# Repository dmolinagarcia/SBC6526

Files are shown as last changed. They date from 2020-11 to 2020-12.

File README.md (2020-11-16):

## SBCv1.sch and SBCv1.brd

These files are the first "production " run of my SBC. It has some issues though:

1. Missing a 3K3 Pull-Up Resistor on the /IRQ line
2. Missing 4 3K3 Pull-Up Resistors on the 4 input buttons
3. LCD connector has to be soldered on the bottom of the PCB, as there's no space on top of it for the connector. Because of this, the cable connected to the LCD has all the even/odd wires interchanged. A quick hack, but works. v2 Will solve this
4. The two left stands for the LCD don't have space either on the PCB, so the build is a bit.. unstable.
5. The power jack is completely disposable. A arduino nano gives enough current for the SBC to work up to 15 Mhz

The adjustable clock works, but it tops at around 17 MHz, beyond that, it won't work at all.

LED2 and LED3 common cathod signals are reversed, solved on this version by cutting the traces and adding some bodge wires.

## TEST5.ino (and RAm595 library)
Arduino code to upload an image to ram. Arduino listens on the serial port for the following commands

- S         : Pulls BE low, disconnecting the 6502 from the bus and enabling the shift registers
- A 0000    : Sets the address bus to 0000
- R 0000    : Reads and returns over serial value at memory location 0000
- W 0000 00 : Writes 00 in memory location 0000
- X         : Pulls BE high, disabling the shift registers and reenabling the 6502. The CPU is then reset and code execution begins
- B 0000 00 000F : Bulk program, staring at 0000 for 000F bytes. Maximum is 1K (0400). Bytes sent to the arduino after this are written sequentially on memory

## RAMFLASHER.java
Java code to program a .bin file to the SBC. Right now, the address and source file are hardcoded.  Requires jSerialComm-2.6.1.jar

## SBC_TEST1.asm
- Current firmware. It implements basic IO functions. Handles the LCD screen with a movable window in memory (0x7000 - 0x7fff). Up and Down buttons move the window. All string funcitions move a virtual cursor through the memory map.
- LCD refresh is implemented via interrupts with VIA Timer. The whole screen is redraw 5 time per sec and the keyboard scanned.
- customizable calls are executed whenever any button is pressed. Memory Location 0x30 contains the pressed key to be read by software.

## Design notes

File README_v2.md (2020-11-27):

# SBC6526
A 6502 based SBC, capable of using a MOS6526, or the new replacement 74HCT6526

Being my first attempt at creating a SBC, v1 had many flaws. There were some pull-up resistors missing, the PCB layout was a mess, the bootstrap code was... well... unreadable to be honest. Moreover, the CAD tool I choose for v1, Eagle Cad, has a nasty licensing which is pulling away many users. I decided to make the transition to KiCAD for the v2. It's still a work in progress, and completely untested, but feel free to take a look if you like.

This readme will be updated as soon as new content is commited to the repository.

## BootStrap

The SBC6526 has no ROM. RAM exists between 0000-7FFF and C000-FFFF. As you know, the 6502 CPU needs the startup vectors to be present in the last segment of memory so, how does the SBC6526 boot?

An Arduino NANO handles the startup sequence. On startup, it brings BE low, disconnecting the 6502 from the address and data busses, and the R/W line. This also enables a pair of 8bit shift registers that handle from now on the address bus.

The RAM IC has 2 enable inputs. One is controled via the SBC Address Decoding logic, the other, directly by the ARDUINO. During BootStraping, RAMCE pulses with PHI2 (independent from the arduino) and the Arduino pulses CE line. This is a bit unorthodox and may cause some failures to write, if the arduino pulse happens when PHI2 is  high. This is handled by trying several times to write.

When the ROM image is written, BE is released, and the 6502 is resetted by the Arduino itself.

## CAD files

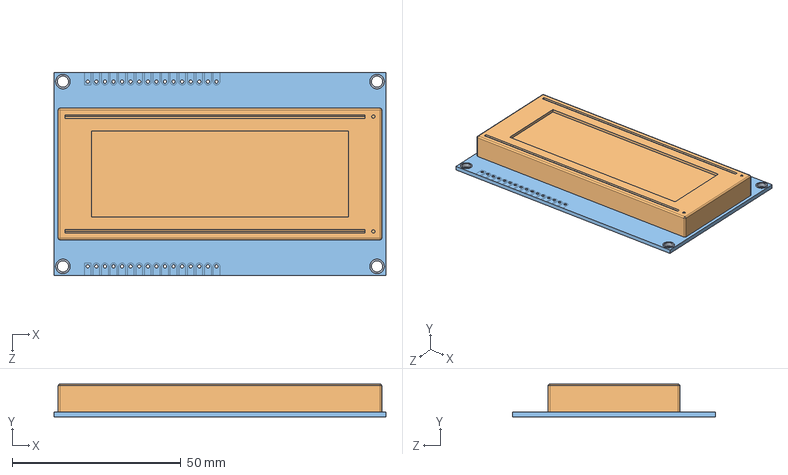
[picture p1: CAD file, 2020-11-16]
v2/kicad/sbc6526.3d/20X4LCD JHD204A.STEP
98.3 x 9.76 x 60.0 mm

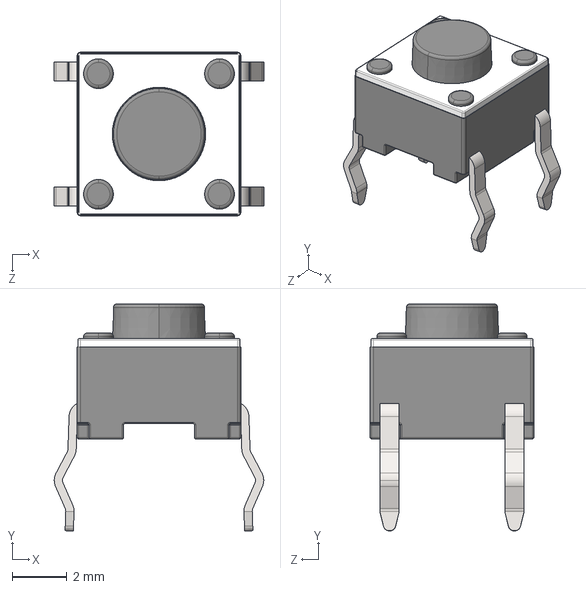
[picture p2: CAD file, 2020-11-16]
v2/kicad/sbc6526.3d/tactileswitch-short.STEP
7.69 x 8.33 x 6.01 mm

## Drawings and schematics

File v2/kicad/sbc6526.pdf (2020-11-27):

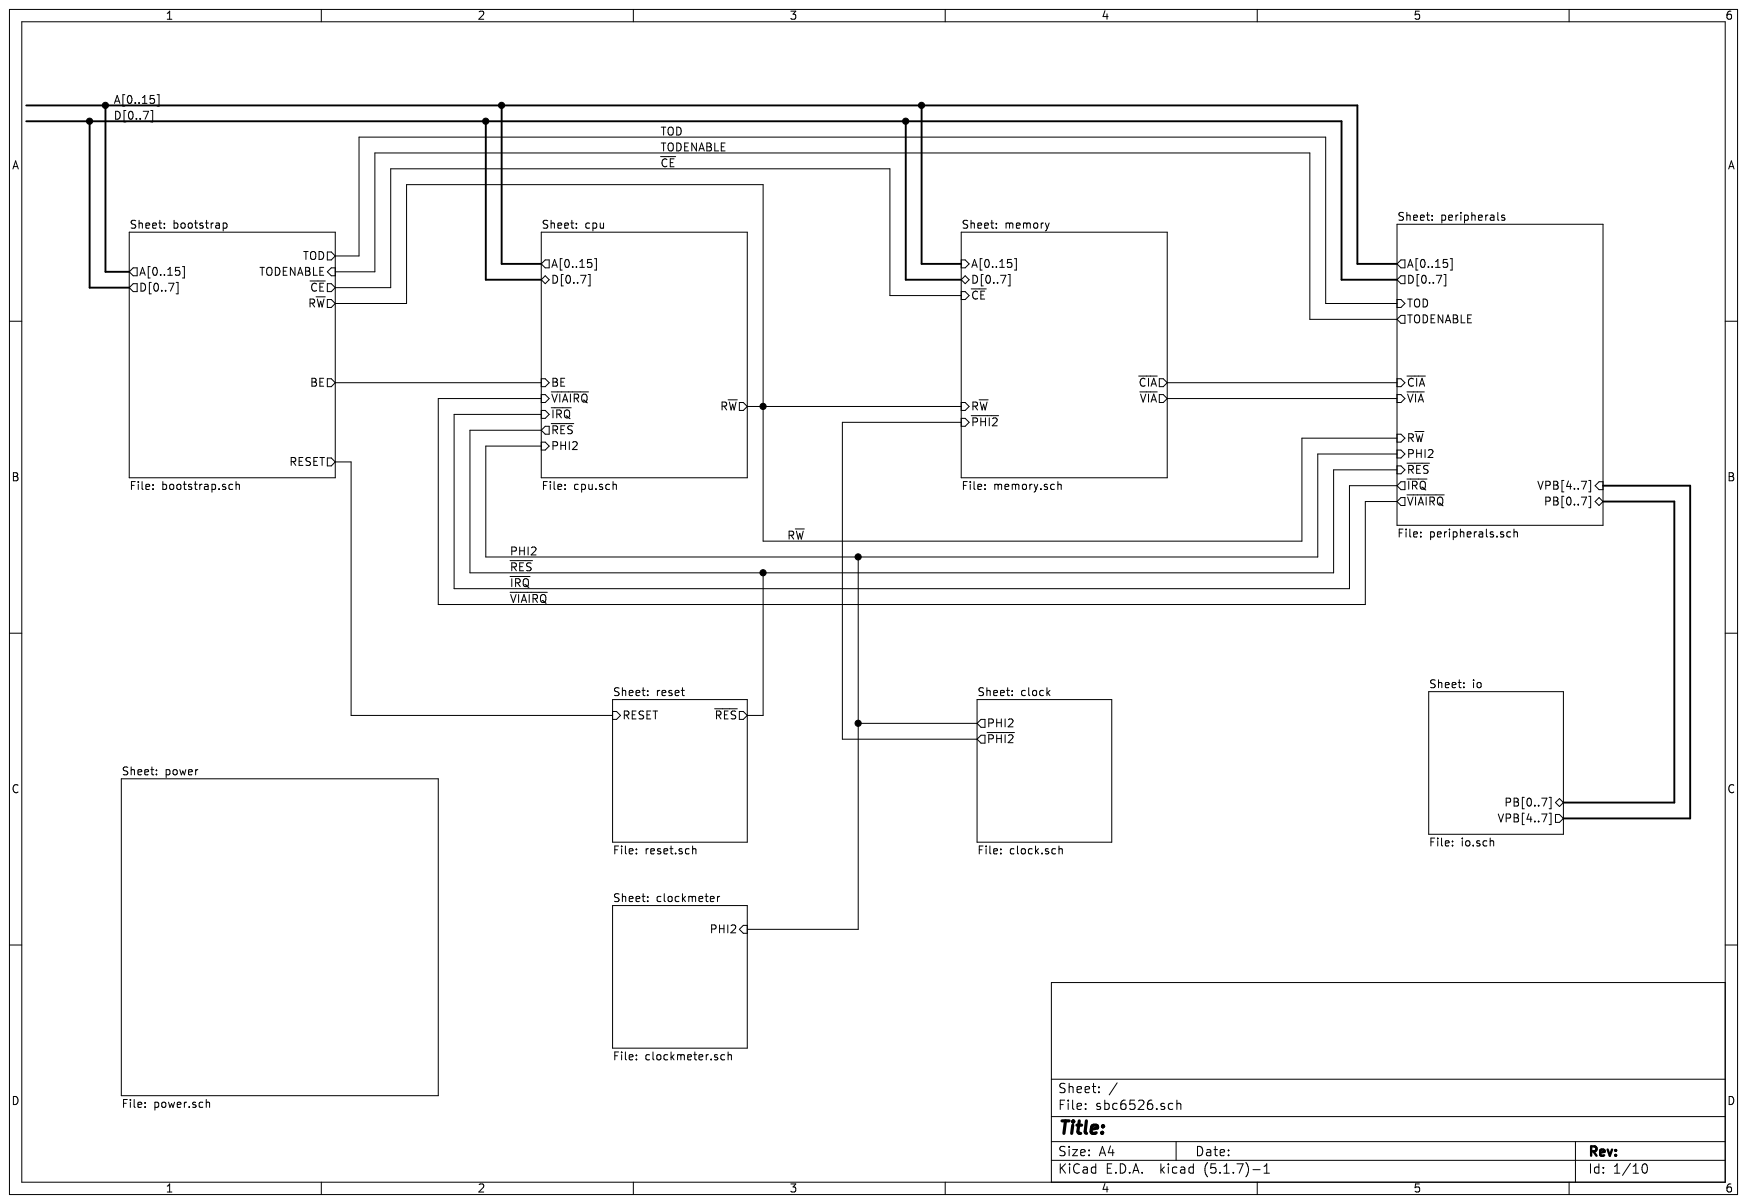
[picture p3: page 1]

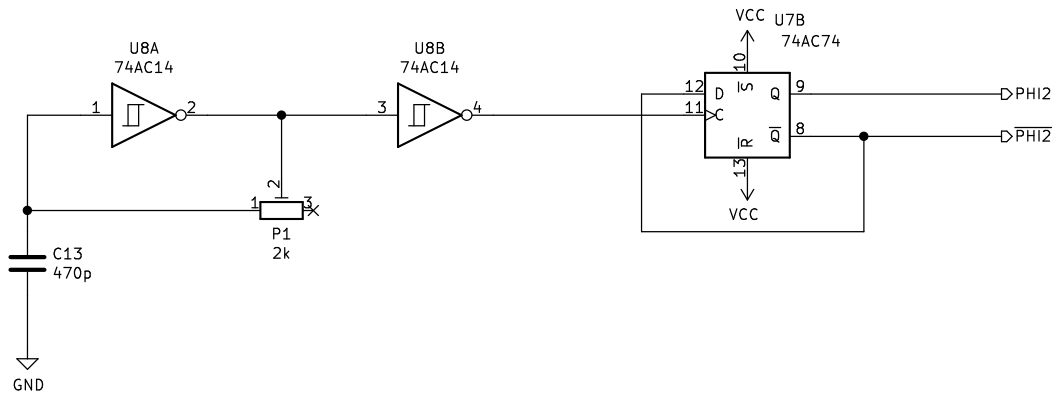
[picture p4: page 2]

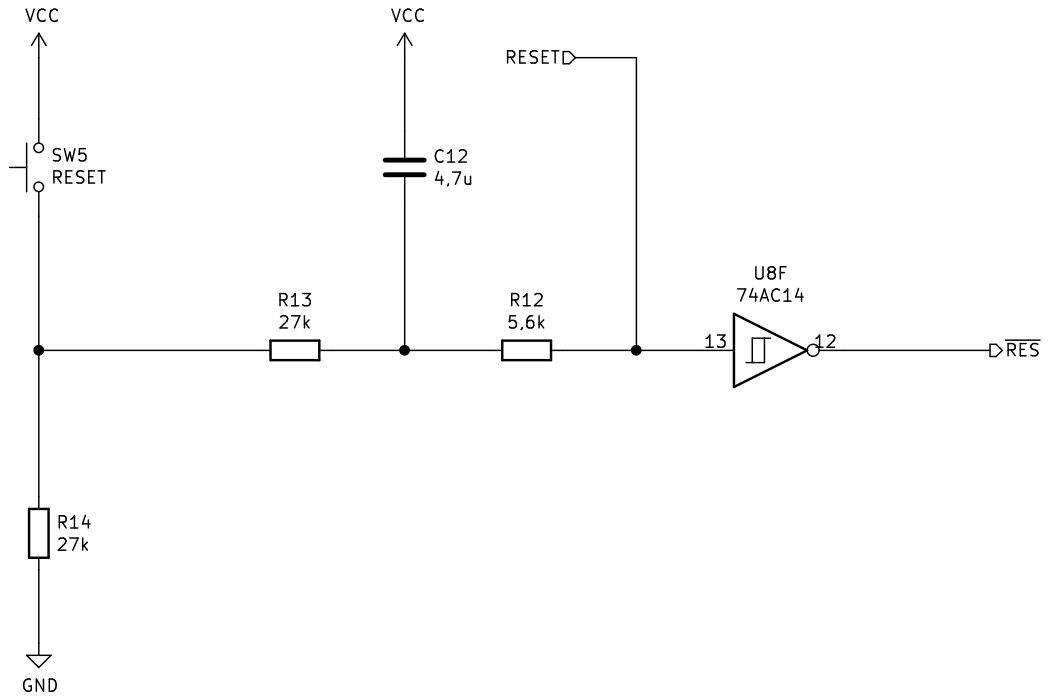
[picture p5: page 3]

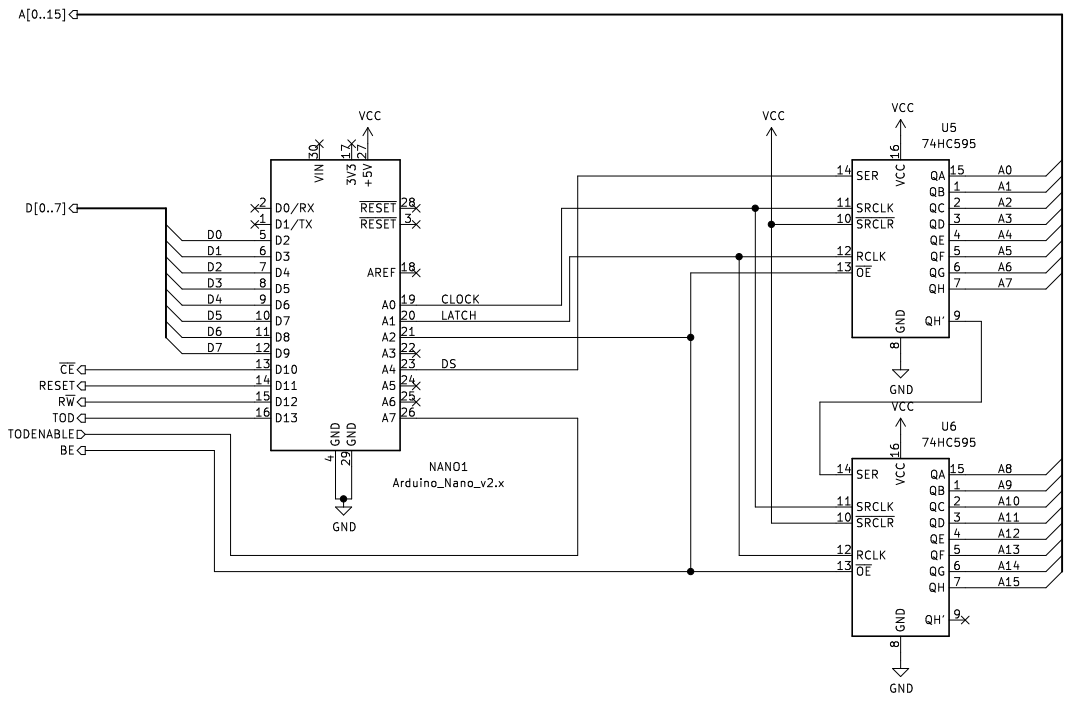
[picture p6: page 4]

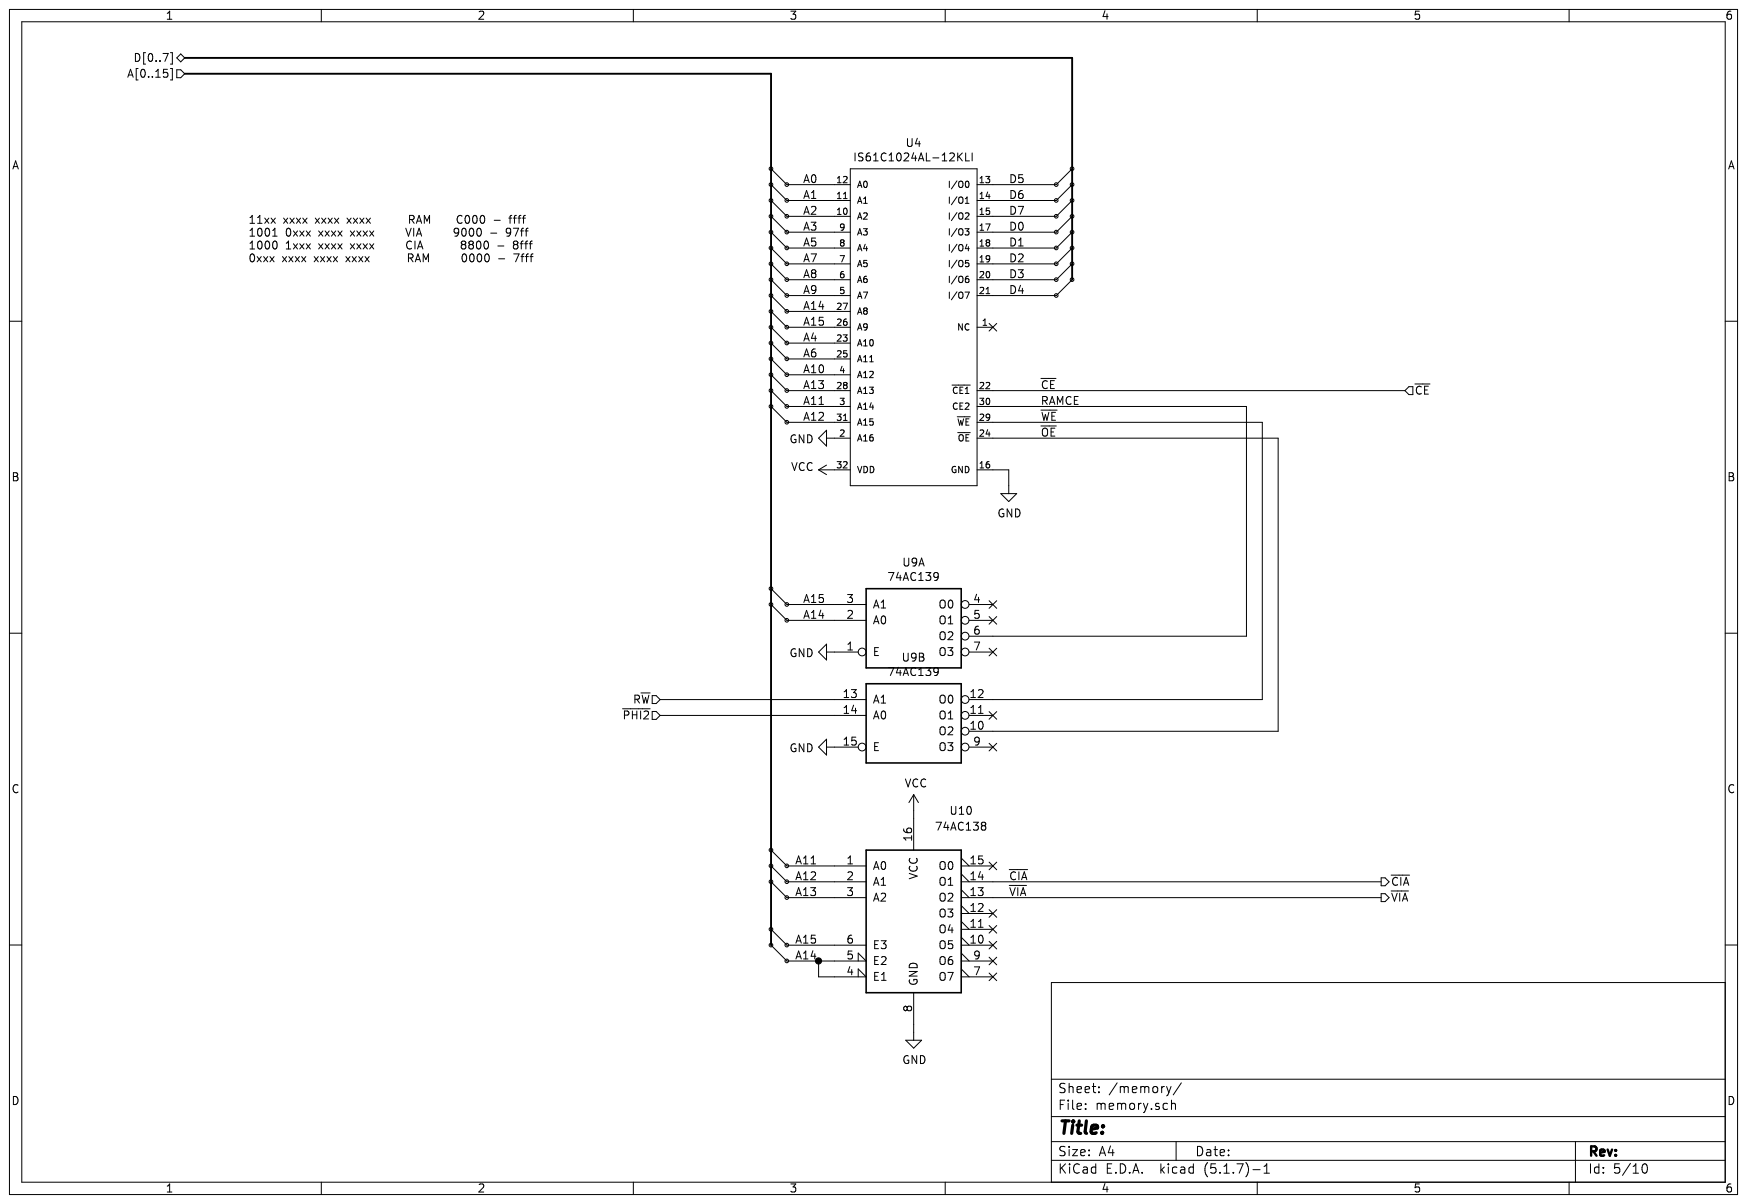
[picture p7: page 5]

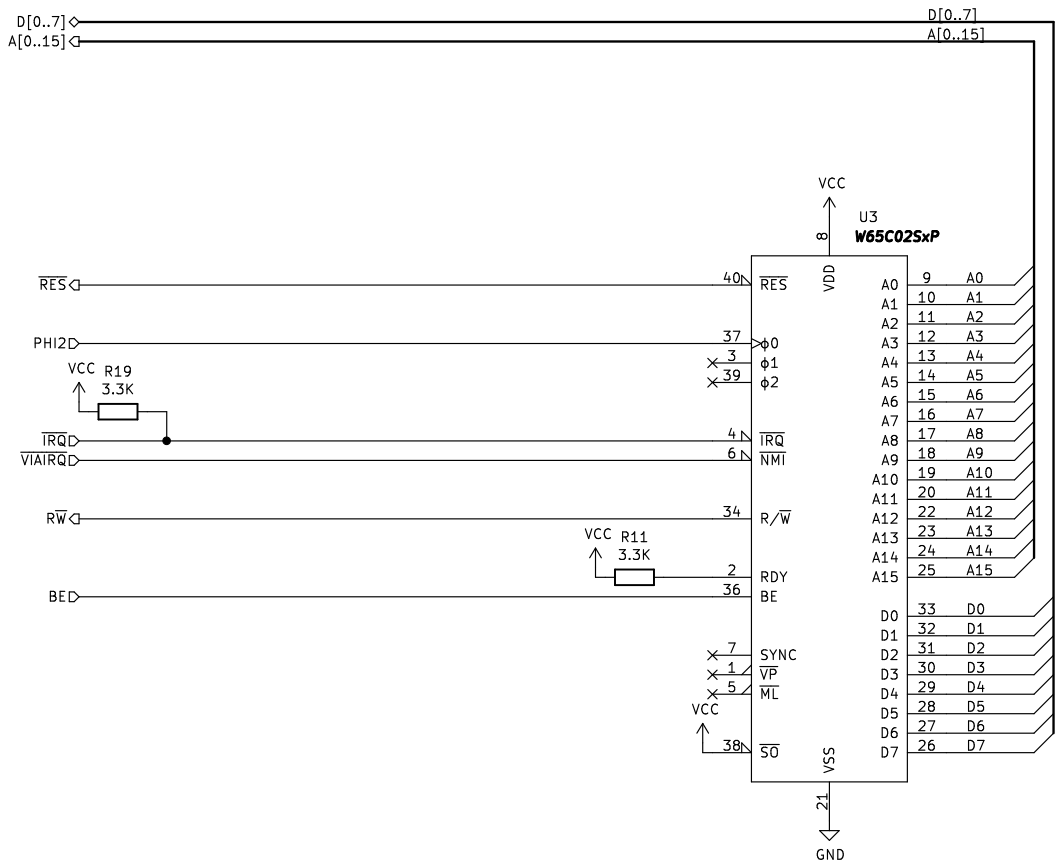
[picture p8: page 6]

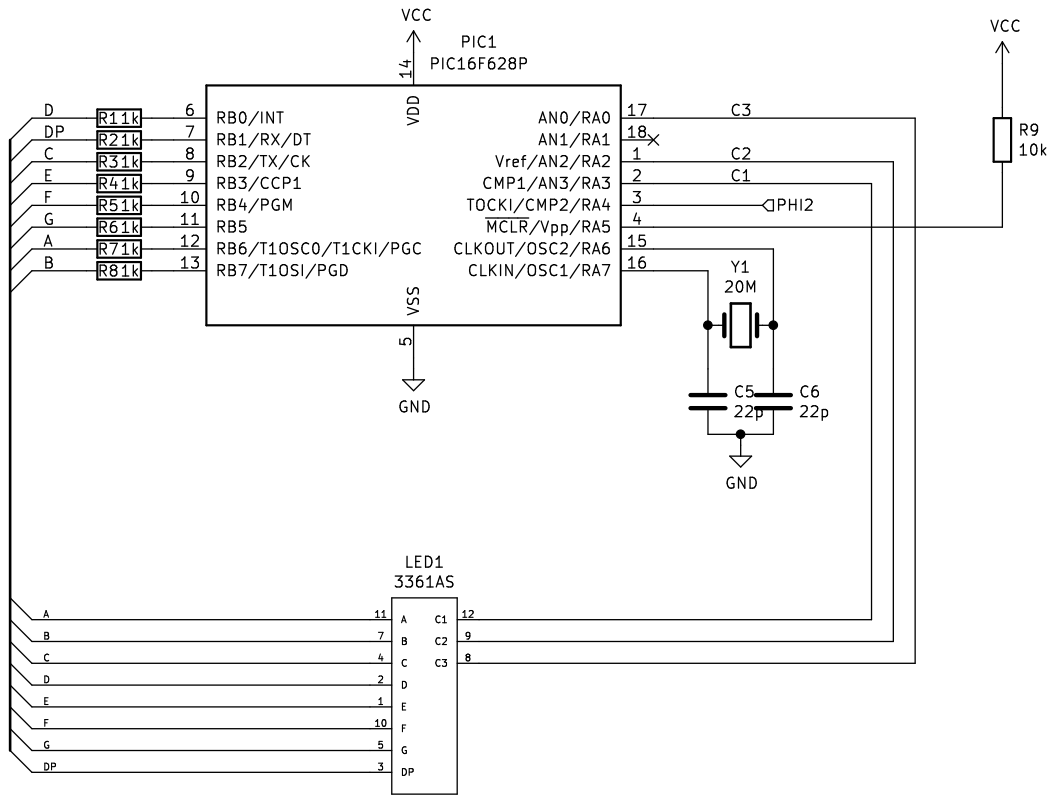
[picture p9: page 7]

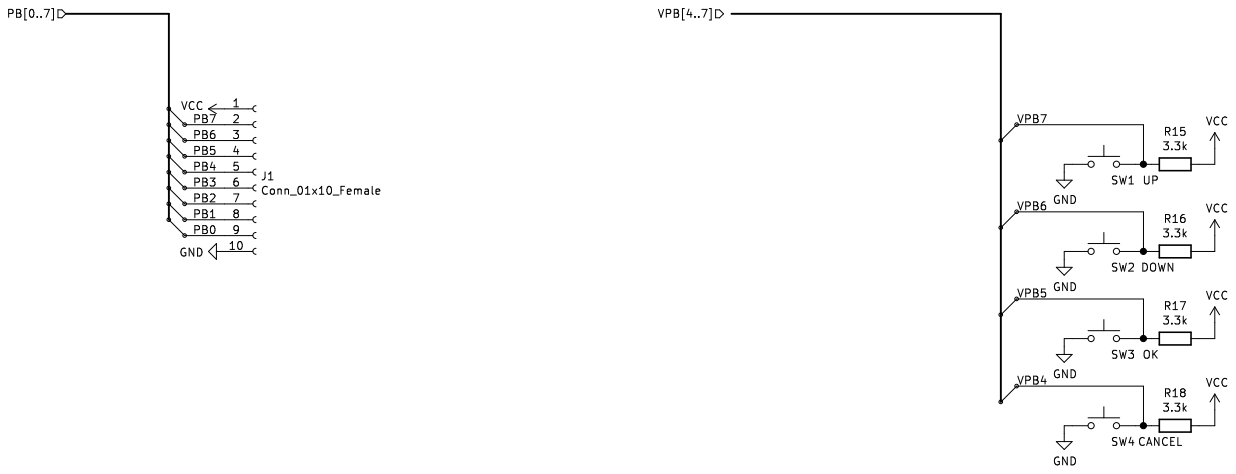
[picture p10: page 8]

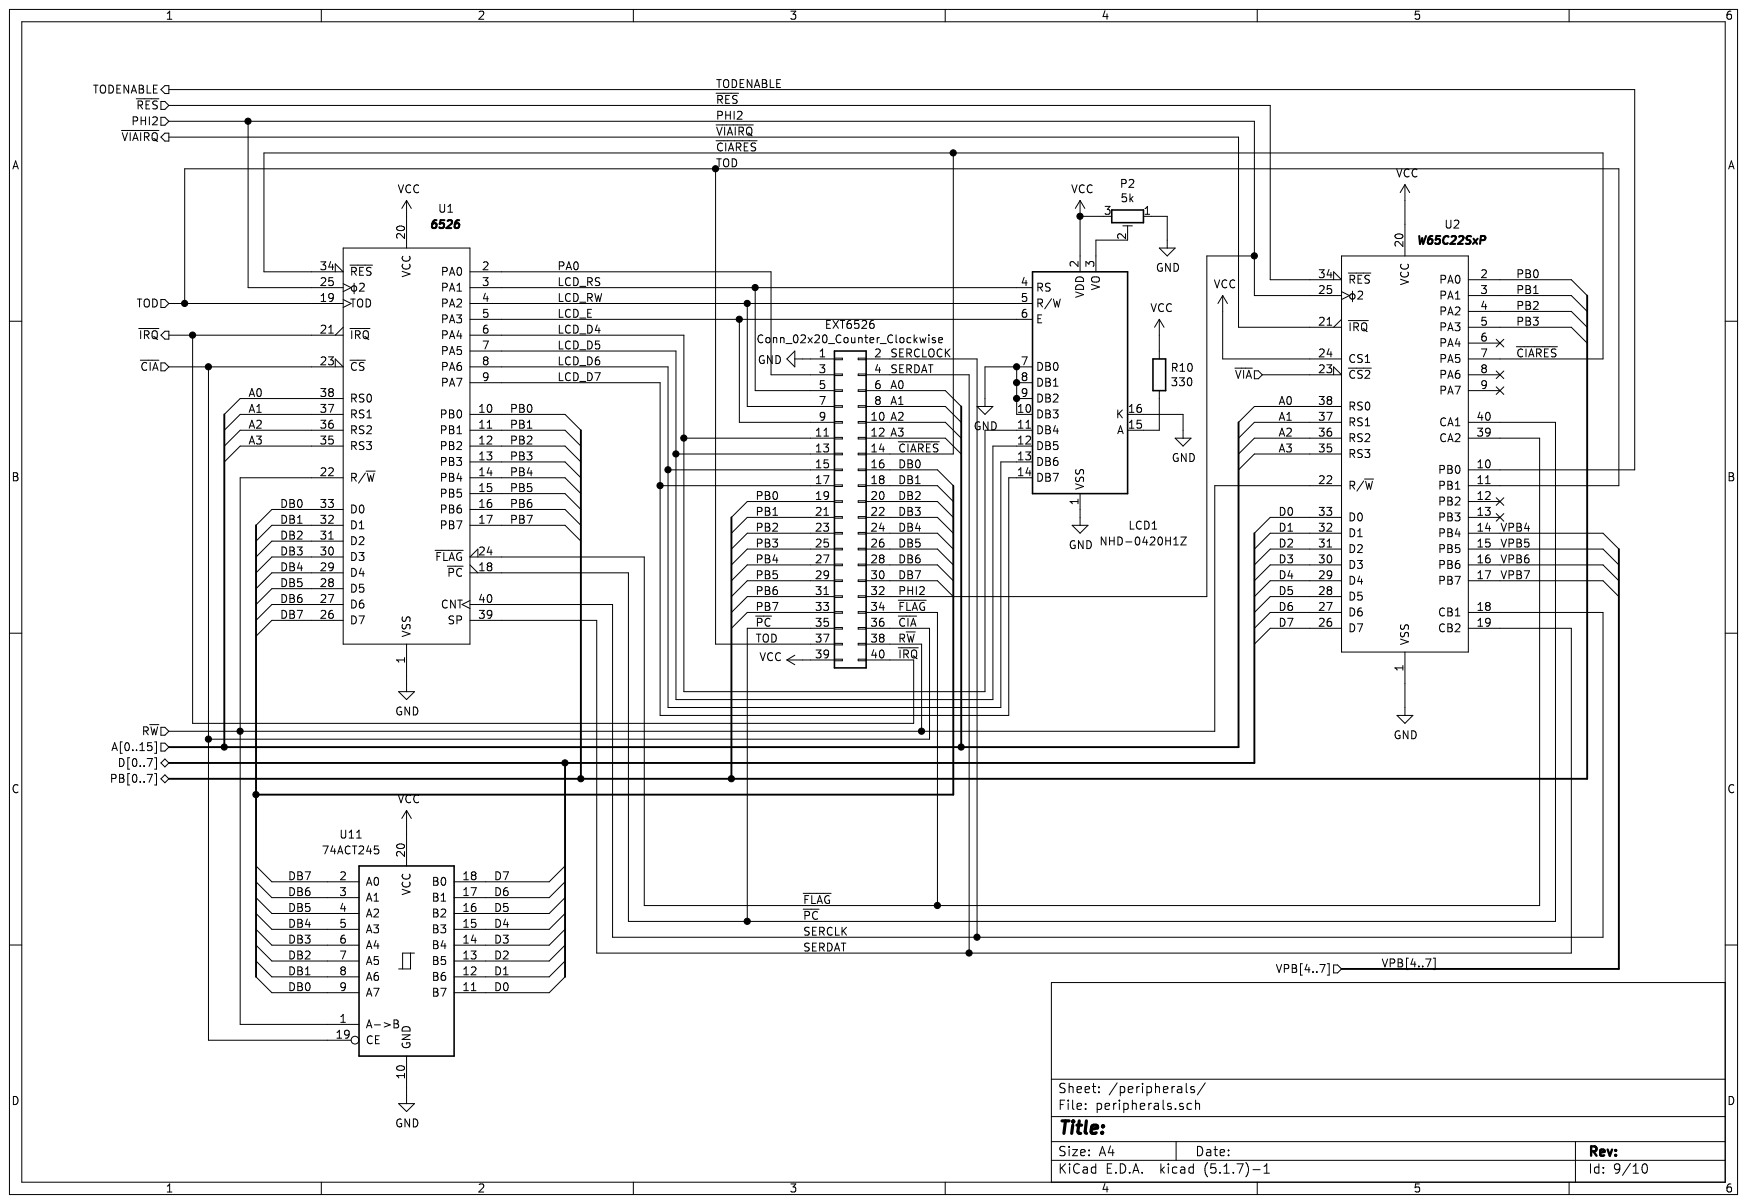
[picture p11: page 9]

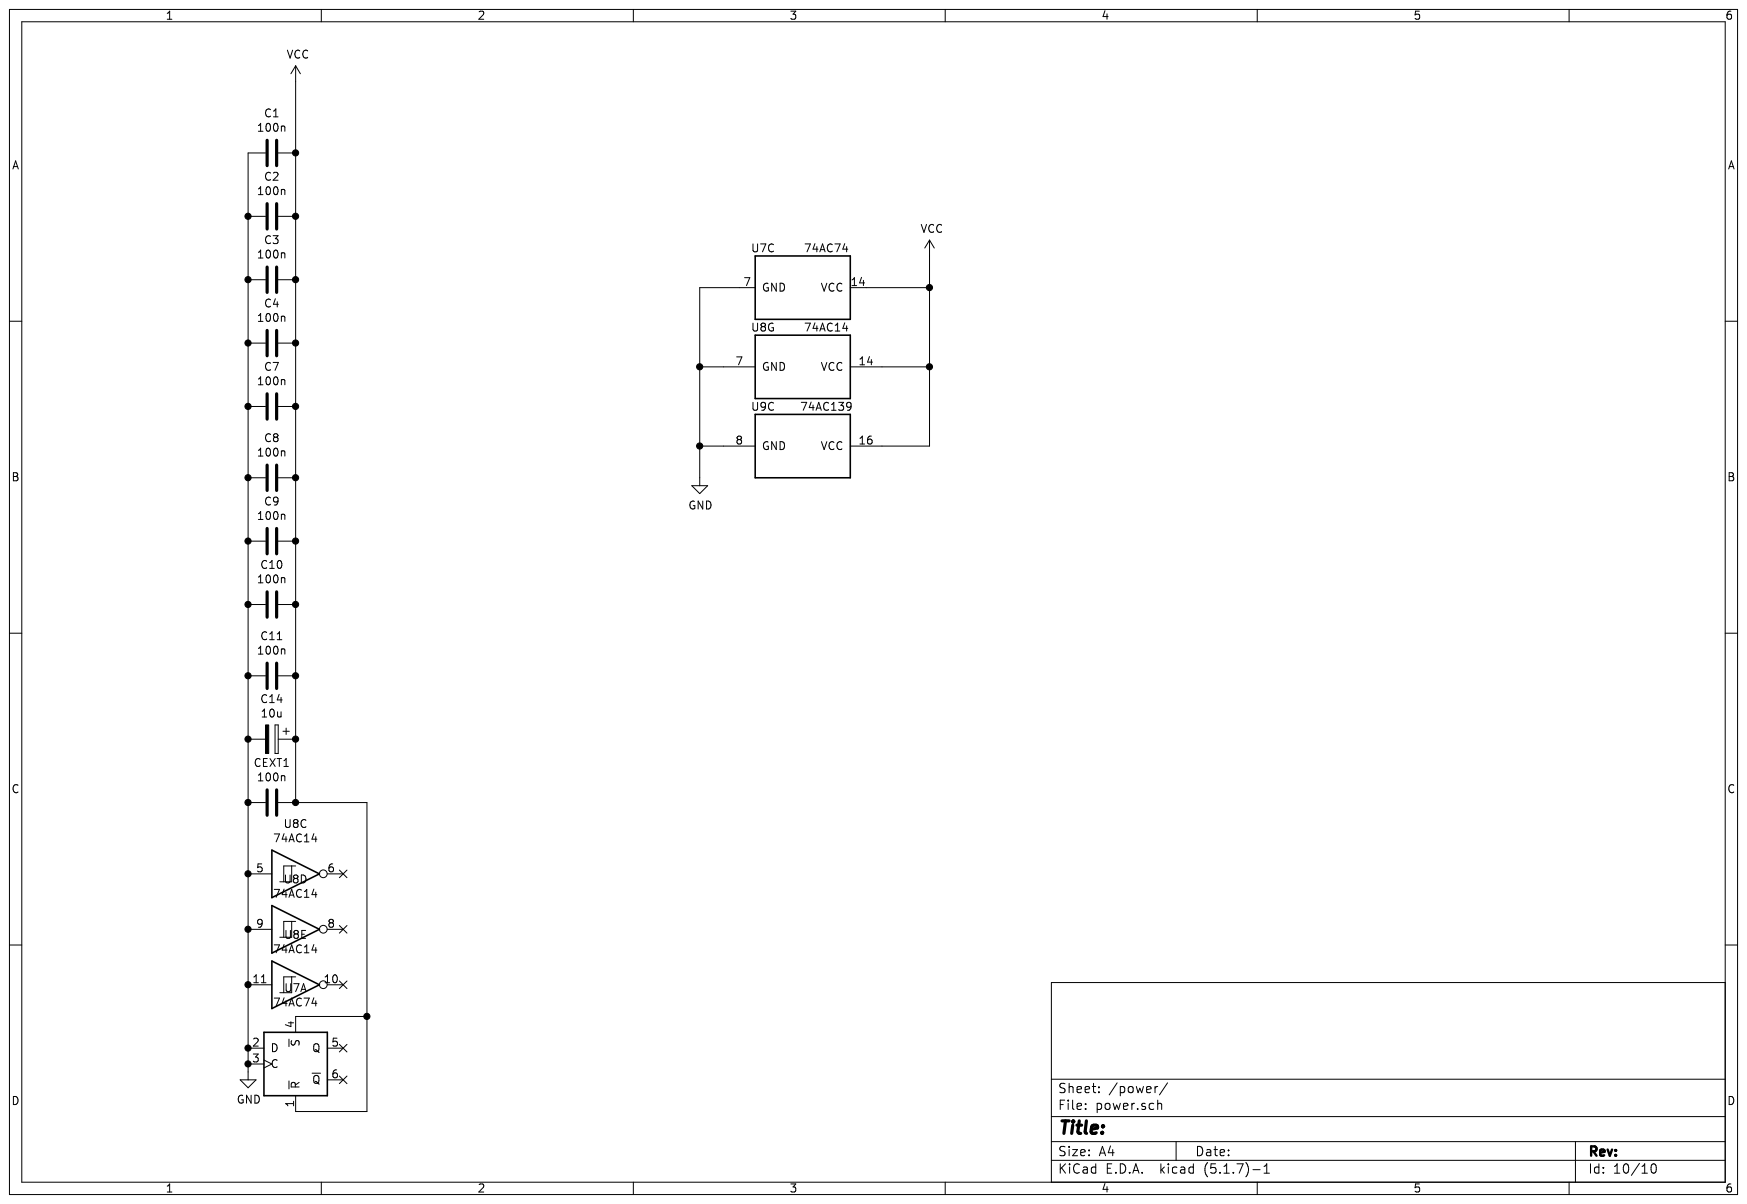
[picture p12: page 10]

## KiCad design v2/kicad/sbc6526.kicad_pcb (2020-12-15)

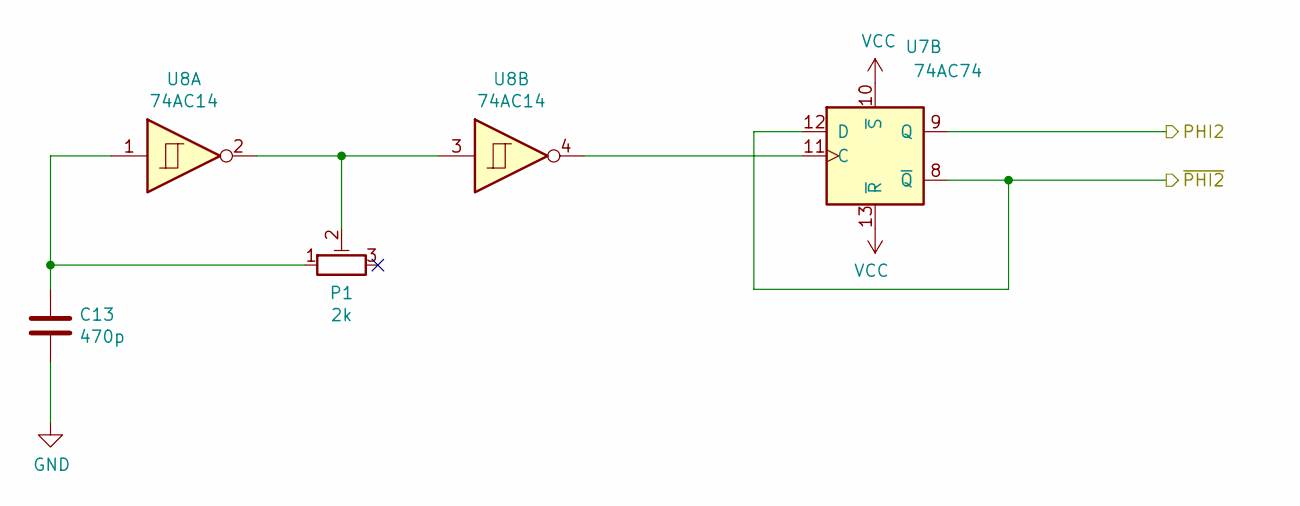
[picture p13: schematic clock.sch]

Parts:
C13: 470p; C_0805_2012Metric_Pad1.18x1.45mm_HandSolder
P1: 2k; Potentiometer_Bourns_3296W_Vertical
U7: 74AC74; SOIC-14_3.9x8.7mm_P1.27mm
U8: 74AC14; SOIC-14_3.9x8.7mm_P1.27mm

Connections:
/PHI2: U7.9 (Q); also elsewhere on the board
/clock/~PHI2: U7.8 (~Q), U7.12 (D); also elsewhere on the board
GND: C13.2; also elsewhere on the board
unnamed: C13.1, P1.1, U8.1
unnamed: P1.2, U8.2, U8.3
unnamed: U7.11 (C), U8.4
VCC: U7.10 (~S), U7.13 (~R); also elsewhere on the board

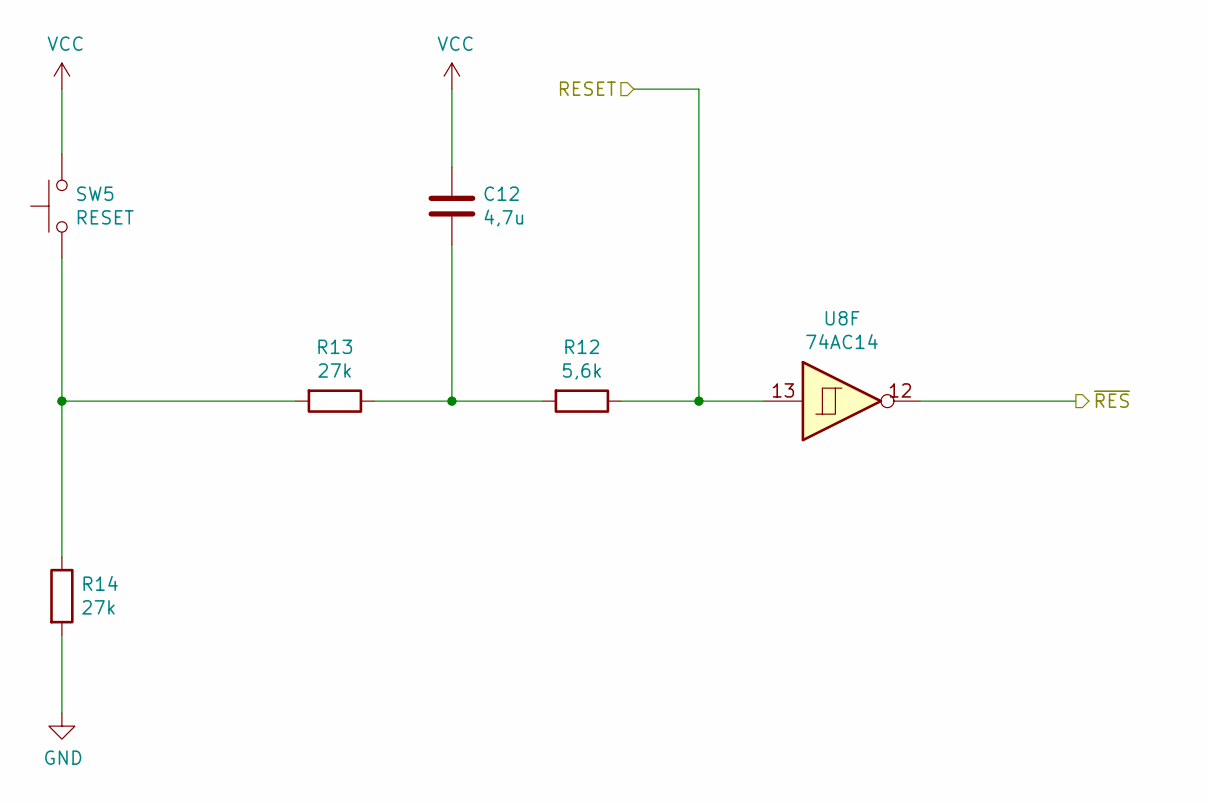
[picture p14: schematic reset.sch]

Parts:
C12: 4,7u; C_0805_2012Metric_Pad1.18x1.45mm_HandSolder
R12: 5,6k; R_0805_2012Metric_Pad1.20x1.40mm_HandSolder
R13, R14: 27k; R_0805_2012Metric_Pad1.20x1.40mm_HandSolder
SW5: RESET; SW_TH_Tactile_Omron_B3F-10xx
U8: 74AC14; SOIC-14_3.9x8.7mm_P1.27mm

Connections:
/bootstrap/RESET: R12.1, U8.13; also elsewhere on the board
/~RES: U8.12; also elsewhere on the board
GND: R14.2; also elsewhere on the board
unnamed: C12.2, R12.2, R13.1
unnamed: R13.2, R14.1, SW5.1 (A), SW5.2 (A)
VCC: C12.1, SW5.3 (B), SW5.4 (B); also elsewhere on the board

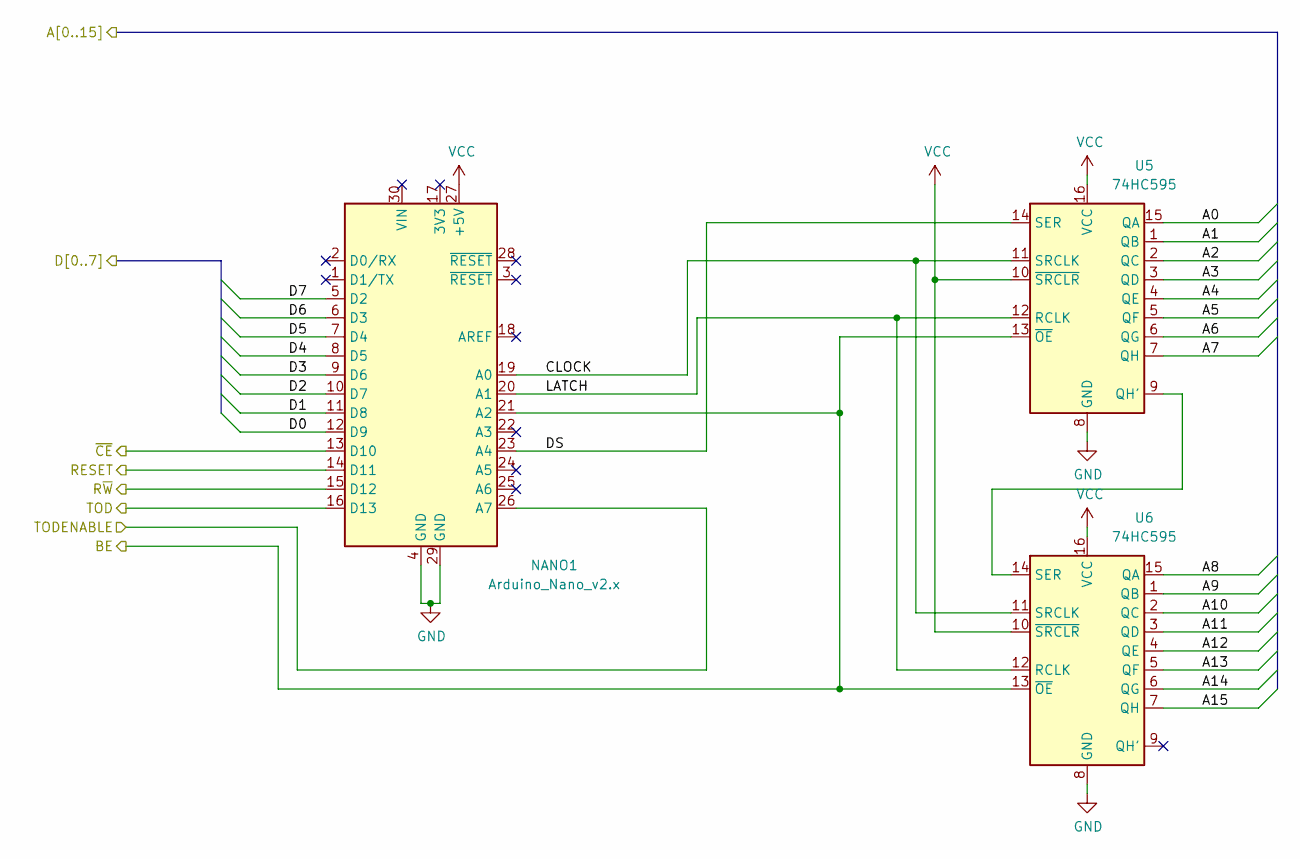
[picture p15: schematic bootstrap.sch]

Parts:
NANO1: Arduino_Nano_v2.x; Arduino_Nano
U5, U6: 74HC595; SOIC-16_3.9x9.9mm_P1.27mm

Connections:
/R~W: NANO1.15 (D12); also elsewhere on the board
/TOD: NANO1.16 (D13); also elsewhere on the board
/TODENABLE: NANO1.26 (A7); also elsewhere on the board
/bootstrap/A0: U5.15 (QA); also elsewhere on the board
/bootstrap/A1: U5.1 (QB); also elsewhere on the board
/bootstrap/A2: U5.2 (QC); also elsewhere on the board
/bootstrap/A3: U5.3 (QD); also elsewhere on the board
/bootstrap/A4: U5.4 (QE); also elsewhere on the board
/bootstrap/A5: U5.5 (QF); also elsewhere on the board
/bootstrap/A6: U5.6 (QG); also elsewhere on the board
/bootstrap/A7: U5.7 (QH); also elsewhere on the board
/bootstrap/A8: U6.15 (QA); also elsewhere on the board
/bootstrap/A9: U6.1 (QB); also elsewhere on the board
/bootstrap/A10: U6.2 (QC); also elsewhere on the board
/bootstrap/A11: U6.3 (QD); also elsewhere on the board
/bootstrap/A12: U6.4 (QE); also elsewhere on the board
/bootstrap/A13: U6.5 (QF); also elsewhere on the board
/bootstrap/A14: U6.6 (QG); also elsewhere on the board
/bootstrap/A15: U6.7 (QH); also elsewhere on the board
/bootstrap/BE: NANO1.21 (A2), U5.13 (~OE), U6.13 (~OE); also elsewhere on the board
/bootstrap/CLOCK: NANO1.19 (A0), U5.11 (SRCLK), U6.11 (SRCLK)
/bootstrap/D0: NANO1.12 (D9); also elsewhere on the board
/bootstrap/D1: NANO1.11 (D8); also elsewhere on the board
/bootstrap/D2: NANO1.10 (D7); also elsewhere on the board
/bootstrap/D3: NANO1.9 (D6); also elsewhere on the board
/bootstrap/D4: NANO1.8 (D5); also elsewhere on the board
/bootstrap/D5: NANO1.7 (D4); also elsewhere on the board
/bootstrap/D6: NANO1.6 (D3); also elsewhere on the board
/bootstrap/D7: NANO1.5 (D2); also elsewhere on the board
/bootstrap/DS: NANO1.23 (A4), U5.14 (SER)
/bootstrap/LATCH: NANO1.20 (A1), U5.12 (RCLK), U6.12 (RCLK)
/bootstrap/RESET: NANO1.14 (D11); also elsewhere on the board
/~CE: NANO1.13 (D10); also elsewhere on the board
GND: NANO1.4 (GND), NANO1.29 (GND), U5.8 (GND), U6.8 (GND); also elsewhere on the board
unnamed: U5.9 (QH'), U6.14 (SER)
VCC: NANO1.27 (+5V), U5.10 (~SRCLR), U5.16 (VCC), U6.10 (~SRCLR), U6.16 (VCC); also elsewhere on the board

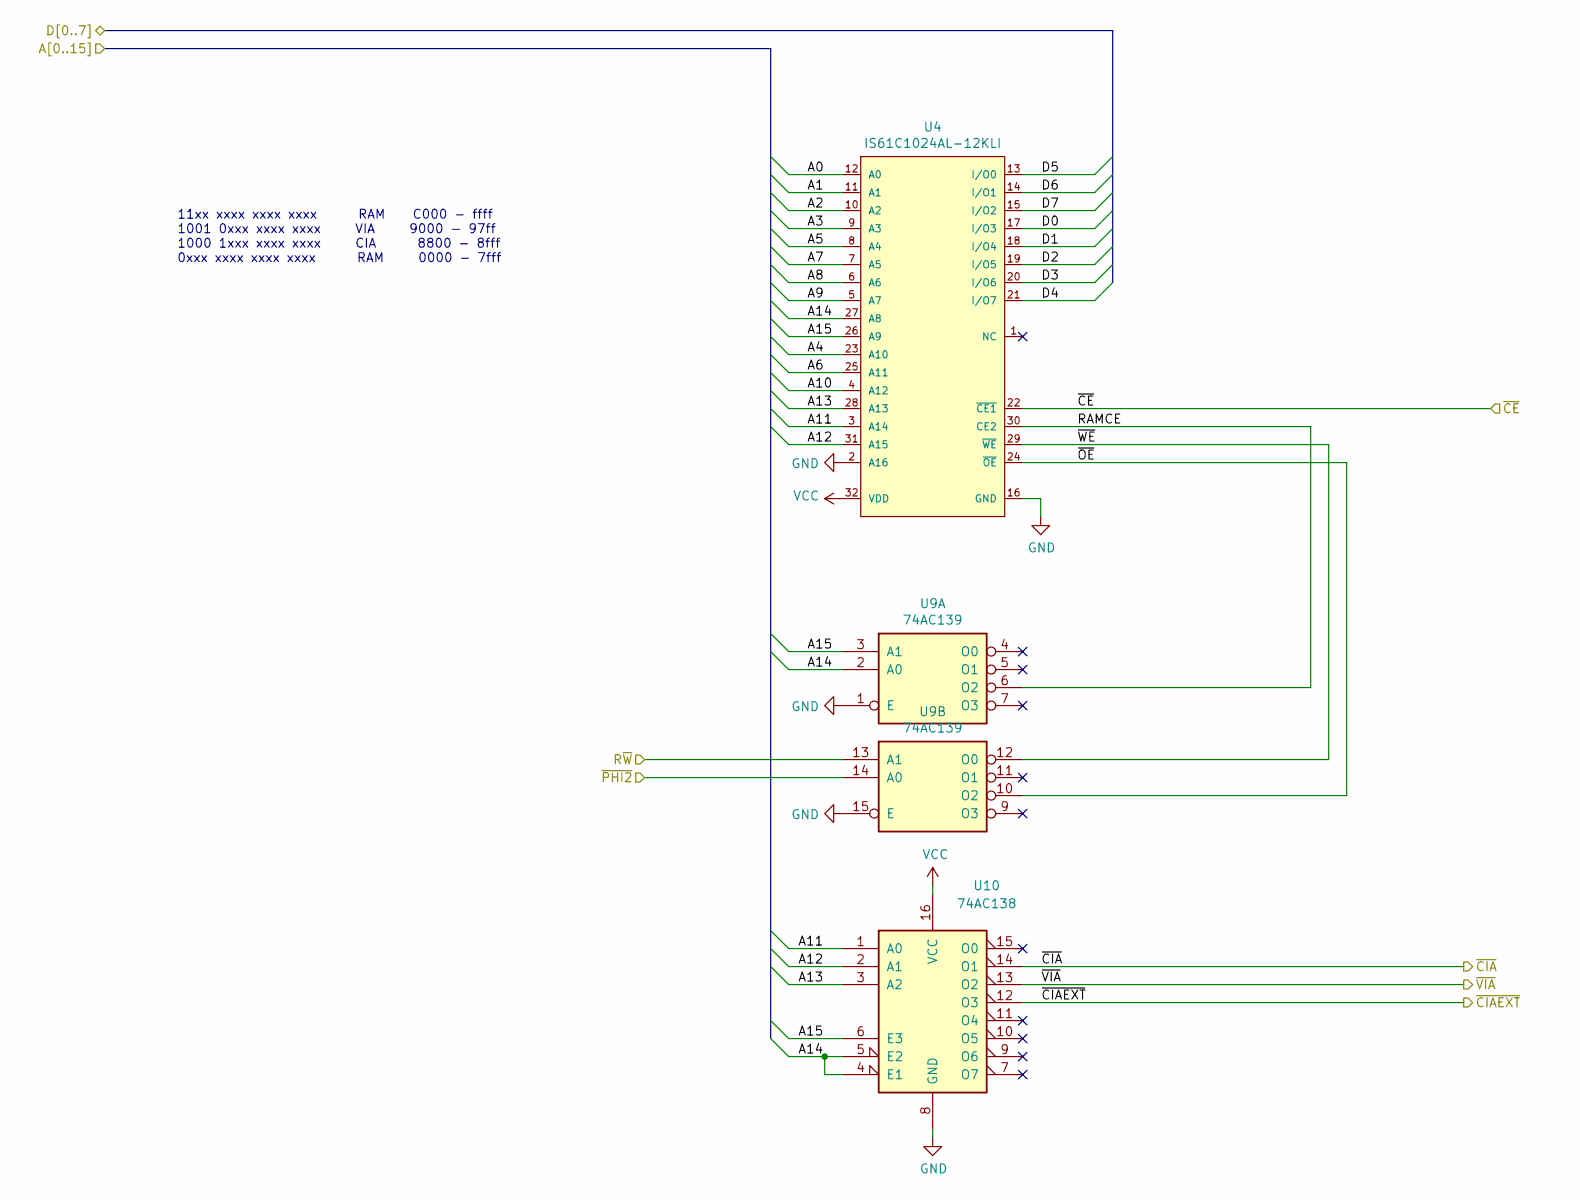
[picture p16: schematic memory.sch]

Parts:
U4: IS61C1024AL-12KLI; SOJ-32_10.16x21.08mm_P1.27mm
U9: 74AC139; SOIC-16_3.9x9.9mm_P1.27mm
U10: 74AC138; SOIC-16_3.9x9.9mm_P1.27mm

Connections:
/R~W: U9.13 (A1); also elsewhere on the board
/bootstrap/A0: U4.12 (A0); also elsewhere on the board
/bootstrap/A1: U4.11 (A1); also elsewhere on the board
/bootstrap/A2: U4.10 (A2); also elsewhere on the board
/bootstrap/A3: U4.9 (A3); also elsewhere on the board
/bootstrap/A4: U4.23 (A10); also elsewhere on the board
/bootstrap/A5: U4.8 (A4); also elsewhere on the board
/bootstrap/A6: U4.25 (A11); also elsewhere on the board
/bootstrap/A7: U4.7 (A5); also elsewhere on the board
/bootstrap/A8: U4.6 (A6); also elsewhere on the board
/bootstrap/A9: U4.5 (A7); also elsewhere on the board
/bootstrap/A10: U4.4 (A12); also elsewhere on the board
/bootstrap/A11: U4.3 (A14), U10.1 (A0); also elsewhere on the board
/bootstrap/A12: U4.31 (A15), U10.2 (A1); also elsewhere on the board
/bootstrap/A13: U4.28 (A13), U10.3 (A2); also elsewhere on the board
/bootstrap/A14: U4.27 (A8), U9.2 (A0), U10.4 (E1), U10.5 (E2); also elsewhere on the board
/bootstrap/A15: U4.26 (A9), U9.3 (A1), U10.6 (E3); also elsewhere on the board
/bootstrap/D0: U4.17 (I/O3); also elsewhere on the board
/bootstrap/D1: U4.18 (I/O4); also elsewhere on the board
/bootstrap/D2: U4.19 (I/O5); also elsewhere on the board
/bootstrap/D3: U4.20 (I/O6); also elsewhere on the board
/bootstrap/D4: U4.21 (I/O7); also elsewhere on the board
/bootstrap/D5: U4.13 (I/O0); also elsewhere on the board
/bootstrap/D6: U4.14 (I/O1); also elsewhere on the board
/bootstrap/D7: U4.15 (I/O2); also elsewhere on the board
/clock/~PHI2: U9.14 (A0); also elsewhere on the board
/memory/RAMCE: U4.30 (CE2), U9.6 (O2)
/memory/~CIA: U10.14 (O1); also elsewhere on the board
/memory/~CIAEXT: U10.12 (O3); also elsewhere on the board
/memory/~OE: U4.24 (~OE~), U9.10 (O2)
/memory/~VIA: U10.13 (O2); also elsewhere on the board
/memory/~WE: U4.29 (~WE~), U9.12 (O0)
/~CE: U4.22 (~CE1~); also elsewhere on the board
GND: U4.2 (A16), U4.16 (GND), U9.1 (E), U9.15 (E), U10.8 (GND); also elsewhere on the board
VCC: U4.32 (VDD), U10.16 (VCC); also elsewhere on the board

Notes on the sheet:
11xx xxxx xxxx xxxx RAM C000 - ffff 1001 0xxx xxxx xxxx VIA 9000 - 97ff 1000 1xxx xxxx xxxx CIA 8800 - 8fff 0xxx xxxx xxxx xxxx RAM 0000 - 7fff

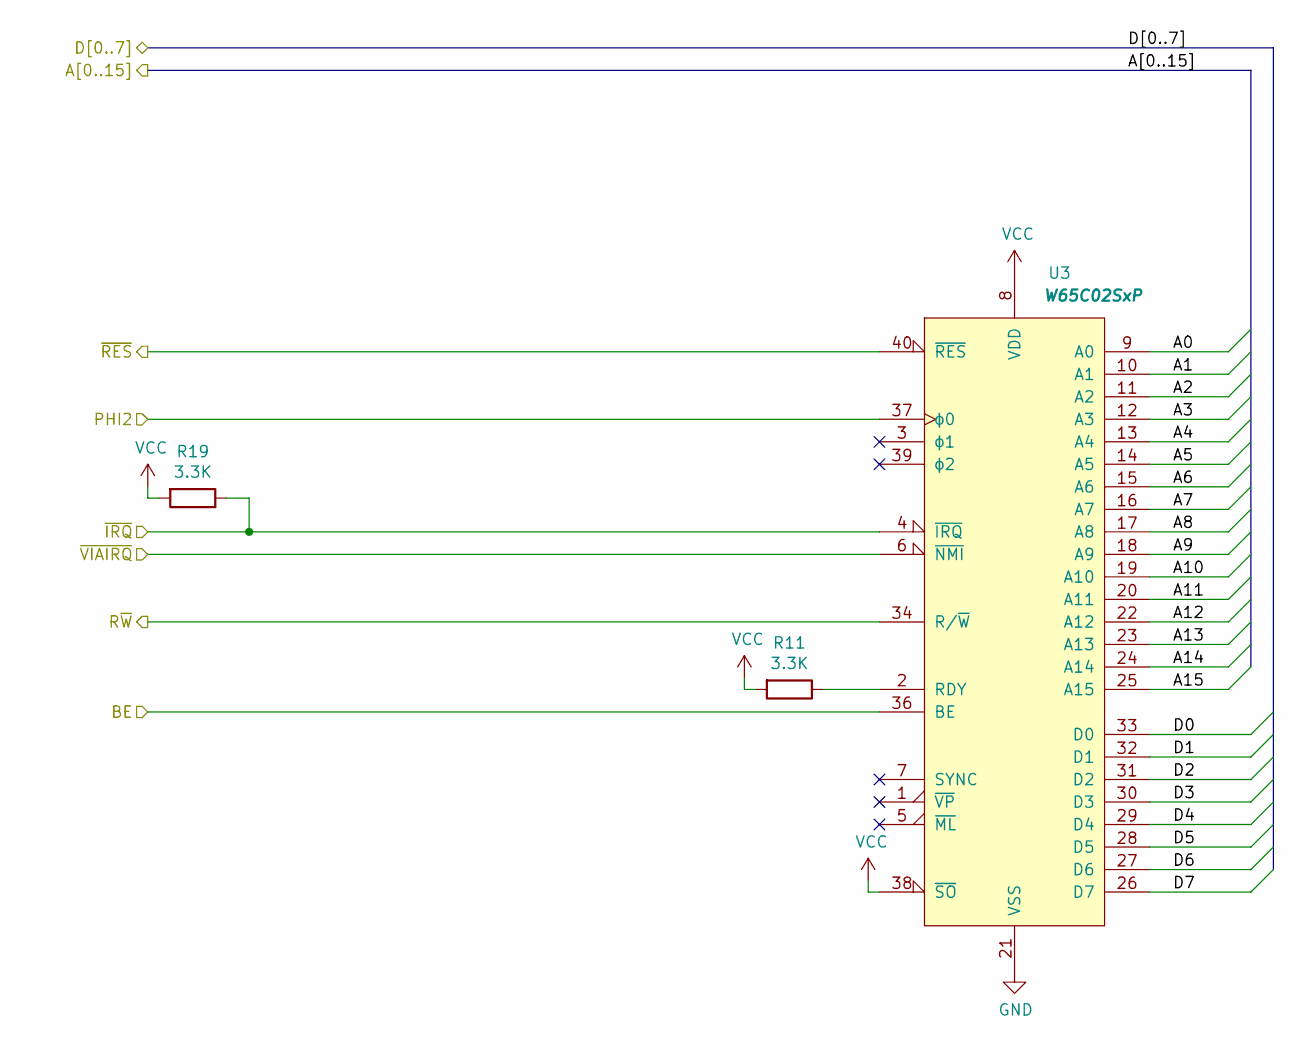
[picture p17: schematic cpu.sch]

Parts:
R11, R19: 3.3K; R_0805_2012Metric_Pad1.20x1.40mm_HandSolder
U3: W65C02SxP; DIP-40_W15.24mm

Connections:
/PHI2: U3.37 (ϕ0); also elsewhere on the board
/R~W: U3.34 (R/~W); also elsewhere on the board
/bootstrap/A0: U3.9 (A0); also elsewhere on the board
/bootstrap/A1: U3.10 (A1); also elsewhere on the board
/bootstrap/A2: U3.11 (A2); also elsewhere on the board
/bootstrap/A3: U3.12 (A3); also elsewhere on the board
/bootstrap/A4: U3.13 (A4); also elsewhere on the board
/bootstrap/A5: U3.14 (A5); also elsewhere on the board
/bootstrap/A6: U3.15 (A6); also elsewhere on the board
/bootstrap/A7: U3.16 (A7); also elsewhere on the board
/bootstrap/A8: U3.17 (A8); also elsewhere on the board
/bootstrap/A9: U3.18 (A9); also elsewhere on the board
/bootstrap/A10: U3.19 (A10); also elsewhere on the board
/bootstrap/A11: U3.20 (A11); also elsewhere on the board
/bootstrap/A12: U3.22 (A12); also elsewhere on the board
/bootstrap/A13: U3.23 (A13); also elsewhere on the board
/bootstrap/A14: U3.24 (A14); also elsewhere on the board
/bootstrap/A15: U3.25 (A15); also elsewhere on the board
/bootstrap/BE: U3.36 (BE); also elsewhere on the board
/bootstrap/D0: U3.33 (D0); also elsewhere on the board
/bootstrap/D1: U3.32 (D1); also elsewhere on the board
/bootstrap/D2: U3.31 (D2); also elsewhere on the board
/bootstrap/D3: U3.30 (D3); also elsewhere on the board
/bootstrap/D4: U3.29 (D4); also elsewhere on the board
/bootstrap/D5: U3.28 (D5); also elsewhere on the board
/bootstrap/D6: U3.27 (D6); also elsewhere on the board
/bootstrap/D7: U3.26 (D7); also elsewhere on the board
/~IRQ: R19.1, U3.4 (~IRQ); also elsewhere on the board
/~RES: U3.40 (~RES); also elsewhere on the board
/~VIAIRQ: U3.6 (~NMI); also elsewhere on the board
GND: U3.21 (VSS); also elsewhere on the board
unnamed: R11.1, U3.2 (RDY)
VCC: R11.2, R19.2, U3.8 (VDD), U3.38 (~SO); also elsewhere on the board

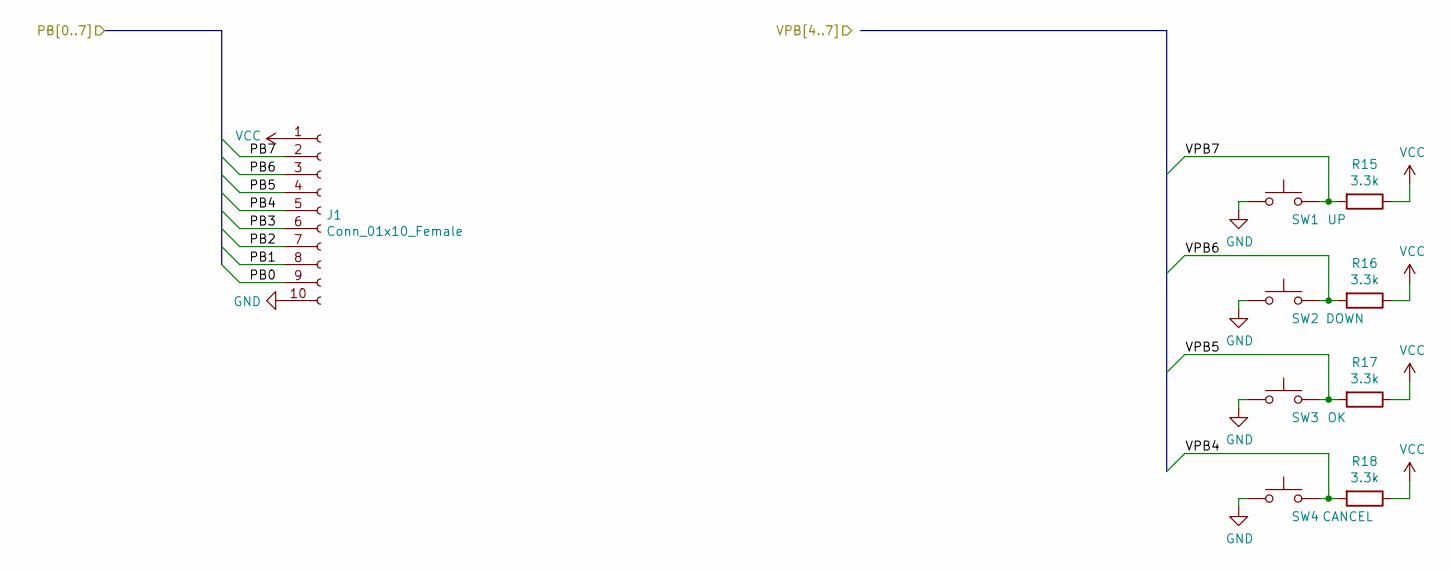
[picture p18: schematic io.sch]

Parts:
J1: Conn_01x10_Female; PinSocket_2x05_P2.54mm_Vertical
R15, R16, R17, R18: 3.3k; R_0805_2012Metric_Pad1.20x1.40mm_HandSolder
SW1: UP; SW_TH_Tactile_Omron_B3F-10xx
SW2: DOWN; SW_TH_Tactile_Omron_B3F-10xx
SW3: OK; SW_TH_Tactile_Omron_B3F-10xx
SW4: CANCEL; SW_TH_Tactile_Omron_B3F-10xx

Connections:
/io/PB0: J1.9; also elsewhere on the board
/io/PB1: J1.8; also elsewhere on the board
/io/PB2: J1.7; also elsewhere on the board
/io/PB3: J1.6; also elsewhere on the board
/io/PB4: J1.5; also elsewhere on the board
/io/PB5: J1.4; also elsewhere on the board
/io/PB6: J1.3; also elsewhere on the board
/io/PB7: J1.2; also elsewhere on the board
/io/VPB4: R18.2, SW4.3 (B), SW4.4 (B); also elsewhere on the board
/io/VPB5: R17.2, SW3.3 (B), SW3.4 (B); also elsewhere on the board
/io/VPB6: R16.2, SW2.3 (B), SW2.4 (B); also elsewhere on the board
/io/VPB7: R15.2, SW1.3 (B), SW1.4 (B); also elsewhere on the board
GND: J1.10, SW1.1 (A), SW1.2 (A), SW2.1 (A), SW2.2 (A), SW3.1 (A), SW3.2 (A), SW4.1 (A), SW4.2 (A); also elsewhere on the board
VCC: J1.1, R15.1, R16.1, R17.1, R18.1; also elsewhere on the board

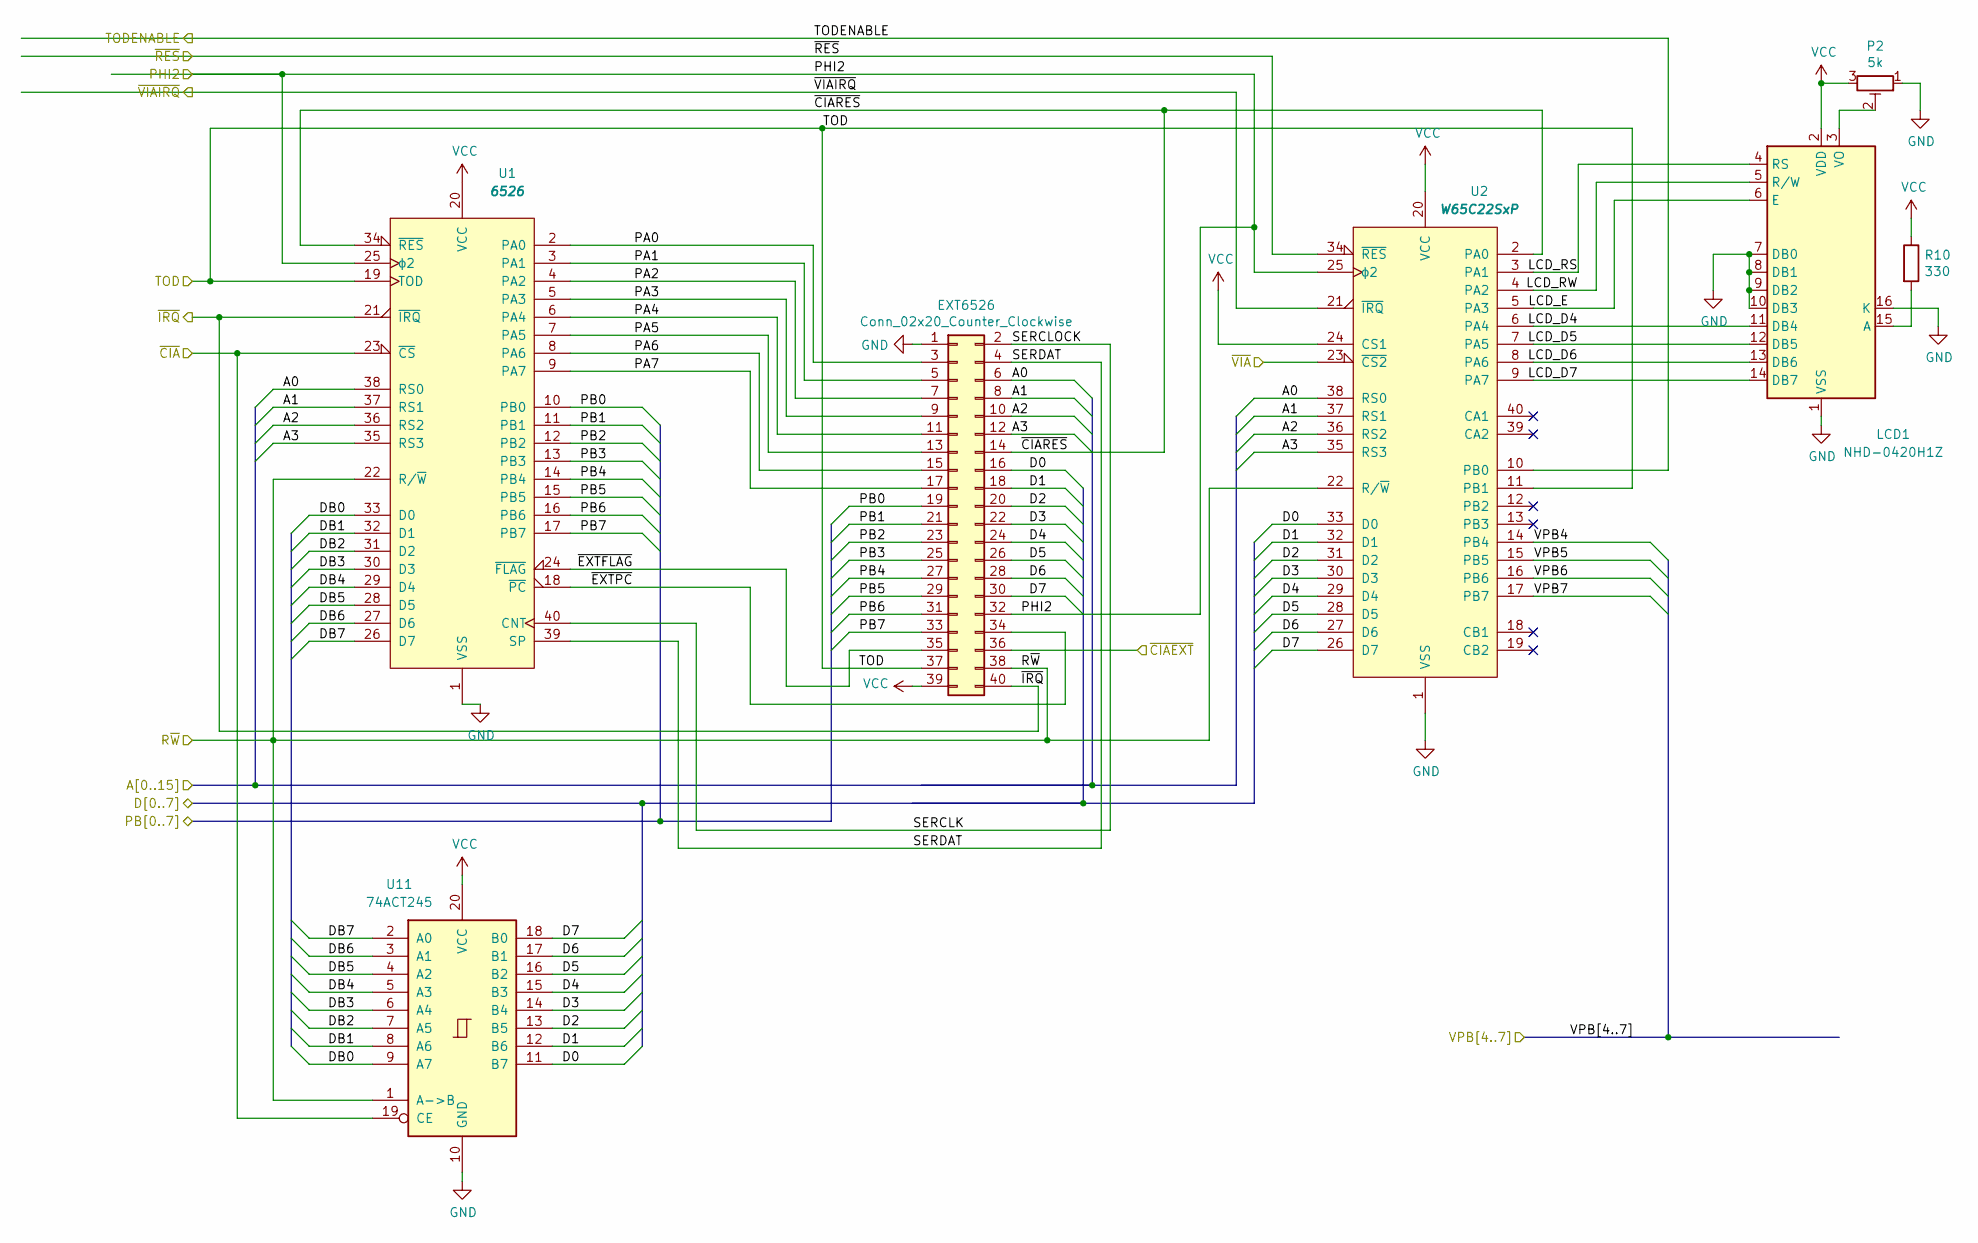
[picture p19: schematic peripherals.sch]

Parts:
EXT6526: Conn_02x20_Counter_Clockwise; PinHeader_2x20_P2.54mm_Vertical
LCD1: NHD-0420H1Z; HD44780_4x20
P2: 5k; Potentiometer_Bourns_3296W_Vertical
R10: 330; R_0805_2012Metric_Pad1.20x1.40mm_HandSolder
U1: 6526; DIP-40_W15.24mm
U2: W65C22SxP; DIP-40_W15.24mm
U11: 74ACT245; DIP-20_W7.62mm

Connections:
/PHI2: EXT6526.32, U1.25 (ϕ2), U2.25 (ϕ2); also elsewhere on the board
/R~W: EXT6526.38, U1.22 (R/~W), U2.22 (R/~W), U11.1 (A->B); also elsewhere on the board
/TOD: EXT6526.37, U1.19 (TOD), U2.11 (PB1); also elsewhere on the board
/TODENABLE: U2.10 (PB0); also elsewhere on the board
/bootstrap/A0: EXT6526.6, U1.38 (RS0), U2.38 (RS0); also elsewhere on the board
/bootstrap/A1: EXT6526.8, U1.37 (RS1), U2.37 (RS1); also elsewhere on the board
/bootstrap/A2: EXT6526.10, U1.36 (RS2), U2.36 (RS2); also elsewhere on the board
/bootstrap/A3: EXT6526.12, U1.35 (RS3), U2.35 (RS3); also elsewhere on the board
/bootstrap/D0: EXT6526.16, U2.33 (D0), U11.11 (B7); also elsewhere on the board
/bootstrap/D1: EXT6526.18, U2.32 (D1), U11.12 (B6); also elsewhere on the board
/bootstrap/D2: EXT6526.20, U2.31 (D2), U11.13 (B5); also elsewhere on the board
/bootstrap/D3: EXT6526.22, U2.30 (D3), U11.14 (B4); also elsewhere on the board
/bootstrap/D4: EXT6526.24, U2.29 (D4), U11.15 (B3); also elsewhere on the board
/bootstrap/D5: EXT6526.26, U2.28 (D5), U11.16 (B2); also elsewhere on the board
/bootstrap/D6: EXT6526.28, U2.27 (D6), U11.17 (B1); also elsewhere on the board
/bootstrap/D7: EXT6526.30, U2.26 (D7), U11.18 (B0); also elsewhere on the board
/io/PB0: EXT6526.19, U1.10 (PB0); also elsewhere on the board
/io/PB1: EXT6526.21, U1.11 (PB1); also elsewhere on the board
/io/PB2: EXT6526.23, U1.12 (PB2); also elsewhere on the board
/io/PB3: EXT6526.25, U1.13 (PB3); also elsewhere on the board
/io/PB4: EXT6526.27, U1.14 (PB4); also elsewhere on the board
/io/PB5: EXT6526.29, U1.15 (PB5); also elsewhere on the board
/io/PB6: EXT6526.31, U1.16 (PB6); also elsewhere on the board
/io/PB7: EXT6526.33, U1.17 (PB7); also elsewhere on the board
/io/VPB4: U2.14 (PB4); also elsewhere on the board
/io/VPB5: U2.15 (PB5); also elsewhere on the board
/io/VPB6: U2.16 (PB6); also elsewhere on the board
/io/VPB7: U2.17 (PB7); also elsewhere on the board
/memory/~CIA: U1.23 (~CS), U11.19 (CE); also elsewhere on the board
/memory/~CIAEXT: EXT6526.36; also elsewhere on the board
/memory/~VIA: U2.23 (~CS2); also elsewhere on the board
/peripherals/DB0: U1.33 (D0), U11.9 (A7)
/peripherals/DB1: U1.32 (D1), U11.8 (A6)
/peripherals/DB2: U1.31 (D2), U11.7 (A5)
/peripherals/DB3: U1.30 (D3), U11.6 (A4)
/peripherals/DB4: U1.29 (D4), U11.5 (A3)
/peripherals/DB5: U1.28 (D5), U11.4 (A2)
/peripherals/DB6: U1.27 (D6), U11.3 (A1)
/peripherals/DB7: U1.26 (D7), U11.2 (A0)
/peripherals/LCD_D4: LCD1.11 (DB4), U2.6 (PA4)
/peripherals/LCD_D5: LCD1.12 (DB5), U2.7 (PA5)
/peripherals/LCD_D6: LCD1.13 (DB6), U2.8 (PA6)
/peripherals/LCD_D7: LCD1.14 (DB7), U2.9 (PA7)
/peripherals/LCD_E: LCD1.6 (E), U2.5 (PA3)
/peripherals/LCD_RS: LCD1.4 (RS), U2.3 (PA1)
/peripherals/LCD_RW: LCD1.5 (R/W), U2.4 (PA2)
/peripherals/PA0: EXT6526.3, U1.2 (PA0)
/peripherals/PA1: EXT6526.5, U1.3 (PA1)
/peripherals/PA2: EXT6526.7, U1.4 (PA2)
/peripherals/PA3: EXT6526.9, U1.5 (PA3)
/peripherals/PA4: EXT6526.11, U1.6 (PA4)
/peripherals/PA5: EXT6526.13, U1.7 (PA5)
/peripherals/PA6: EXT6526.15, U1.8 (PA6)
/peripherals/PA7: EXT6526.17, U1.9 (PA7)
/peripherals/SERCLK: EXT6526.2, U1.40 (CNT)
/peripherals/SERDAT: EXT6526.4, U1.39 (SP)
/peripherals/~CIARES: EXT6526.14, U1.34 (~RES), U2.2 (PA0)
/peripherals/~EXTFLAG: EXT6526.35, U1.24 (~FLAG)
/peripherals/~EXTPC: EXT6526.34, U1.18 (~PC)
/~IRQ: EXT6526.40, U1.21 (~IRQ); also elsewhere on the board
/~RES: U2.34 (~RES); also elsewhere on the board
/~VIAIRQ: U2.21 (~IRQ); also elsewhere on the board
GND: EXT6526.1, LCD1.1 (VSS), LCD1.7 (DB0), LCD1.8 (DB1), LCD1.9 (DB2), LCD1.10 (DB3), LCD1.16 (K), P2.1, U1.1 (VSS), U2.1 (VSS), U11.10 (GND); also elsewhere on the board
unnamed: LCD1.3 (VO), P2.2
unnamed: LCD1.15 (A), R10.2
VCC: EXT6526.39, LCD1.2 (VDD), P2.3, R10.1, U1.20 (VCC), U2.20 (VCC), U2.24 (CS1), U11.20 (VCC); also elsewhere on the board

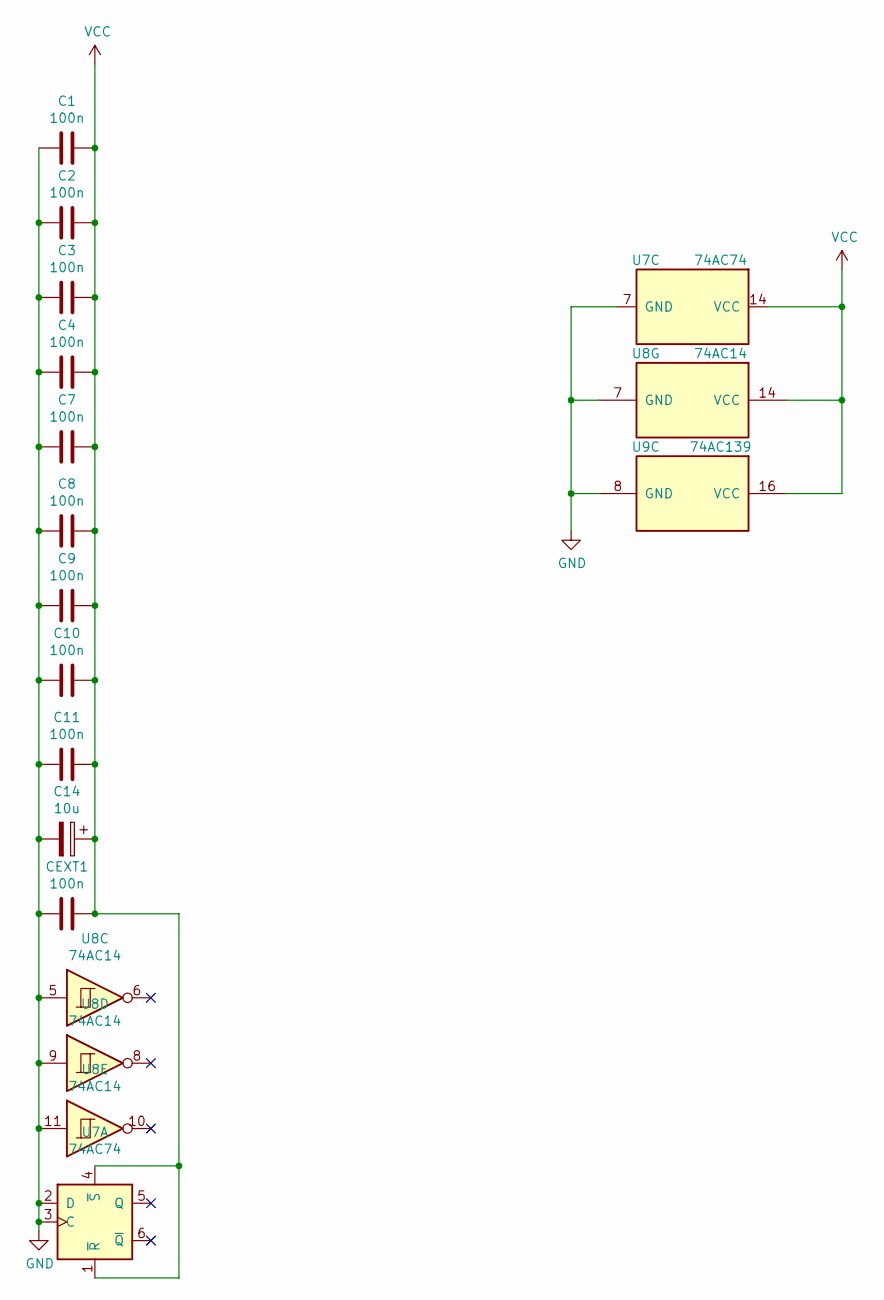
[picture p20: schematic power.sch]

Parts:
C1, C2, C3, C4, C7, C8, C9, C10, C11: 100n; C_0805_2012Metric_Pad1.18x1.45mm_HandSolder
C14: 10u; CP_Radial_D6.3mm_P2.50mm
CEXT1: 100n; C_0805_2012Metric_Pad1.18x1.45mm_HandSolder
U7: 74AC74
U8: 74AC14; SOIC-14_3.9x8.7mm_P1.27mm
U9: 74AC139; SOIC-16_3.9x9.9mm_P1.27mm

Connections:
GND: C1.2, C2.2, C3.2, C4.2, C7.2, C8.2, C9.2, C10.2, C11.2, C14.2, CEXT1.2, U7.2 (D), U7.3 (C), U7.7 (GND), U8.5, U8.7 (GND), U8.9, U8.11, U9.8 (GND); also elsewhere on the board
VCC: C1.1, C2.1, C3.1, C4.1, C7.1, C8.1, C9.1, C10.1, C11.1, C14.1, CEXT1.1, U7.1 (~R), U7.4 (~S), U7.14 (VCC), U8.14 (VCC), U9.16 (VCC); also elsewhere on the board

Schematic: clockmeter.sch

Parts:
C5, C6: 22p; C_0805_2012Metric_Pad1.18x1.45mm_HandSolder
LED1: 3361AS; 3digit-7segment3361
PIC1: PIC16F628P; DIP-18_W7.62mm
R1, R2, R3, R4, R5, R6, R7, R8: 1k; R_0805_2012Metric_Pad1.20x1.40mm_HandSolder
R9: 10k; R_0805_2012Metric_Pad1.20x1.40mm_HandSolder
Y1: 20M; R_Axial_DIN0204_L3.6mm_D1.6mm_P5.08mm_Horizontal

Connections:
/clock/~PHI2: PIC1.3 (TOCKI/CMP2/RA4); also elsewhere on the board
/clockmeter/A: LED1.11 (A), R7.2
/clockmeter/B: LED1.7 (B), R8.2
/clockmeter/C: LED1.4 (C), R3.2
/clockmeter/C1: LED1.12 (C1), PIC1.2 (CMP1/AN3/RA3)
/clockmeter/C2: LED1.9 (C2), PIC1.1 (Vref/AN2/RA2)
/clockmeter/C3: LED1.8 (C3), PIC1.17 (AN0/RA0)
/clockmeter/D: LED1.2 (D), R1.2
/clockmeter/DP: LED1.3 (DP), R2.2
/clockmeter/E: LED1.1 (E), R4.2
/clockmeter/F: LED1.10 (F), R5.2
/clockmeter/G: LED1.5 (G), R6.2
GND: C5.2, C6.2, PIC1.5 (VSS); also elsewhere on the board
unnamed: C5.1, PIC1.16 (CLKIN/OSC1/RA7), Y1.1
unnamed: C6.1, PIC1.15 (CLKOUT/OSC2/RA6), Y1.2
unnamed: PIC1.4 (~MCLR~/Vpp/RA5), R9.2
unnamed: PIC1.6 (RB0/INT), R1.1
unnamed: PIC1.7 (RB1/RX/DT), R2.1
unnamed: PIC1.8 (RB2/TX/CK), R3.1
unnamed: PIC1.9 (RB3/CCP1), R4.1
unnamed: PIC1.10 (RB4/PGM), R5.1
unnamed: PIC1.11 (RB5), R6.1
unnamed: PIC1.12 (RB6/T1OSC0/T1CKI/PGC), R7.1
unnamed: PIC1.13 (RB7/T1OSI/PGD), R8.1
VCC: PIC1.14 (VDD), R9.1; also elsewhere on the board

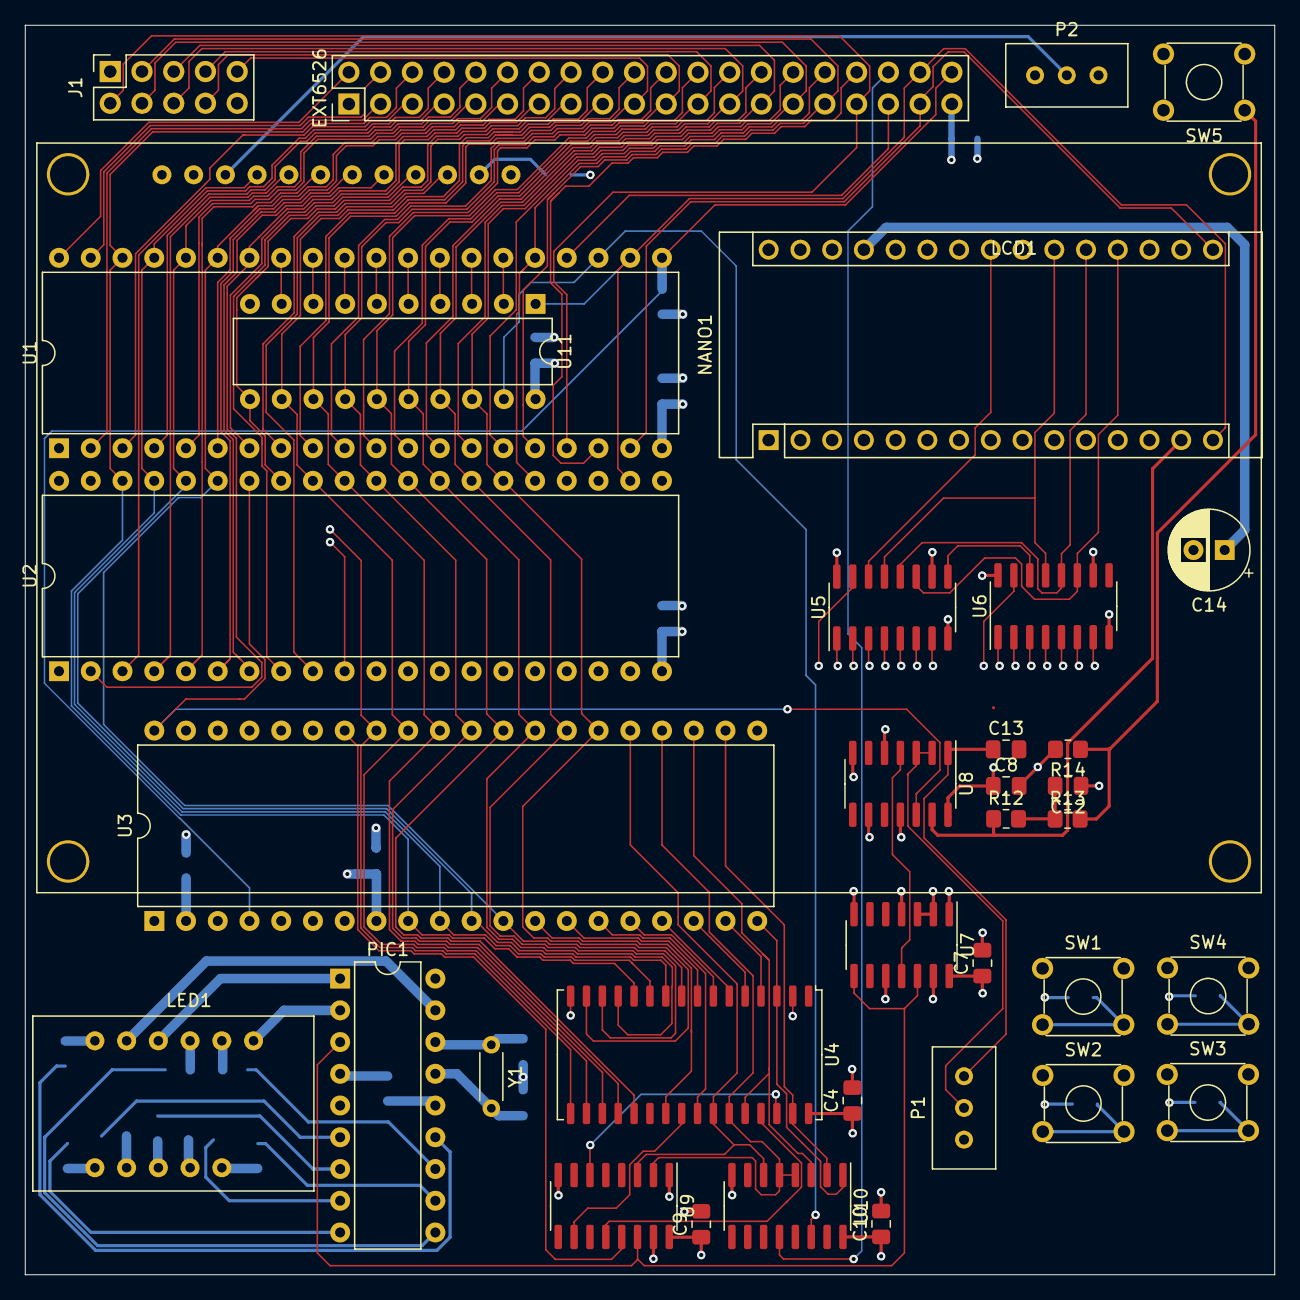
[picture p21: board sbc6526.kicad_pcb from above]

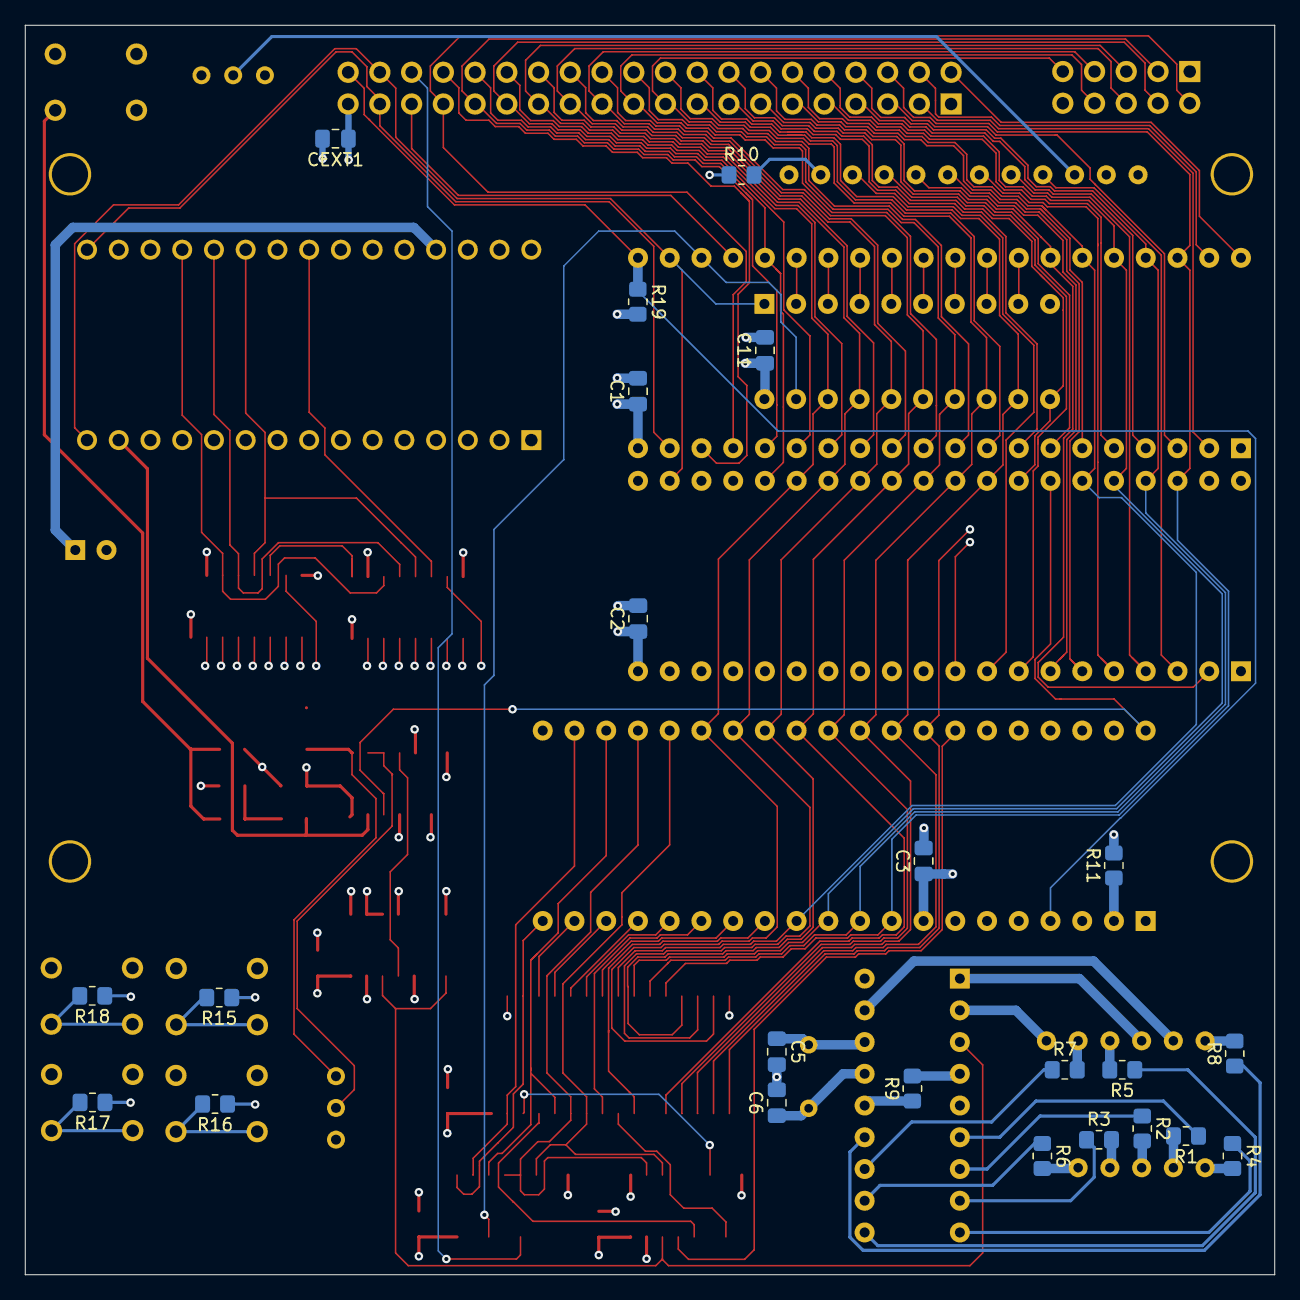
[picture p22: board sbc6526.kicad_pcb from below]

Board: 4 copper layers, 100.0 x 100.0 mm, 59 parts (23 on the bottom side), 117 nets.

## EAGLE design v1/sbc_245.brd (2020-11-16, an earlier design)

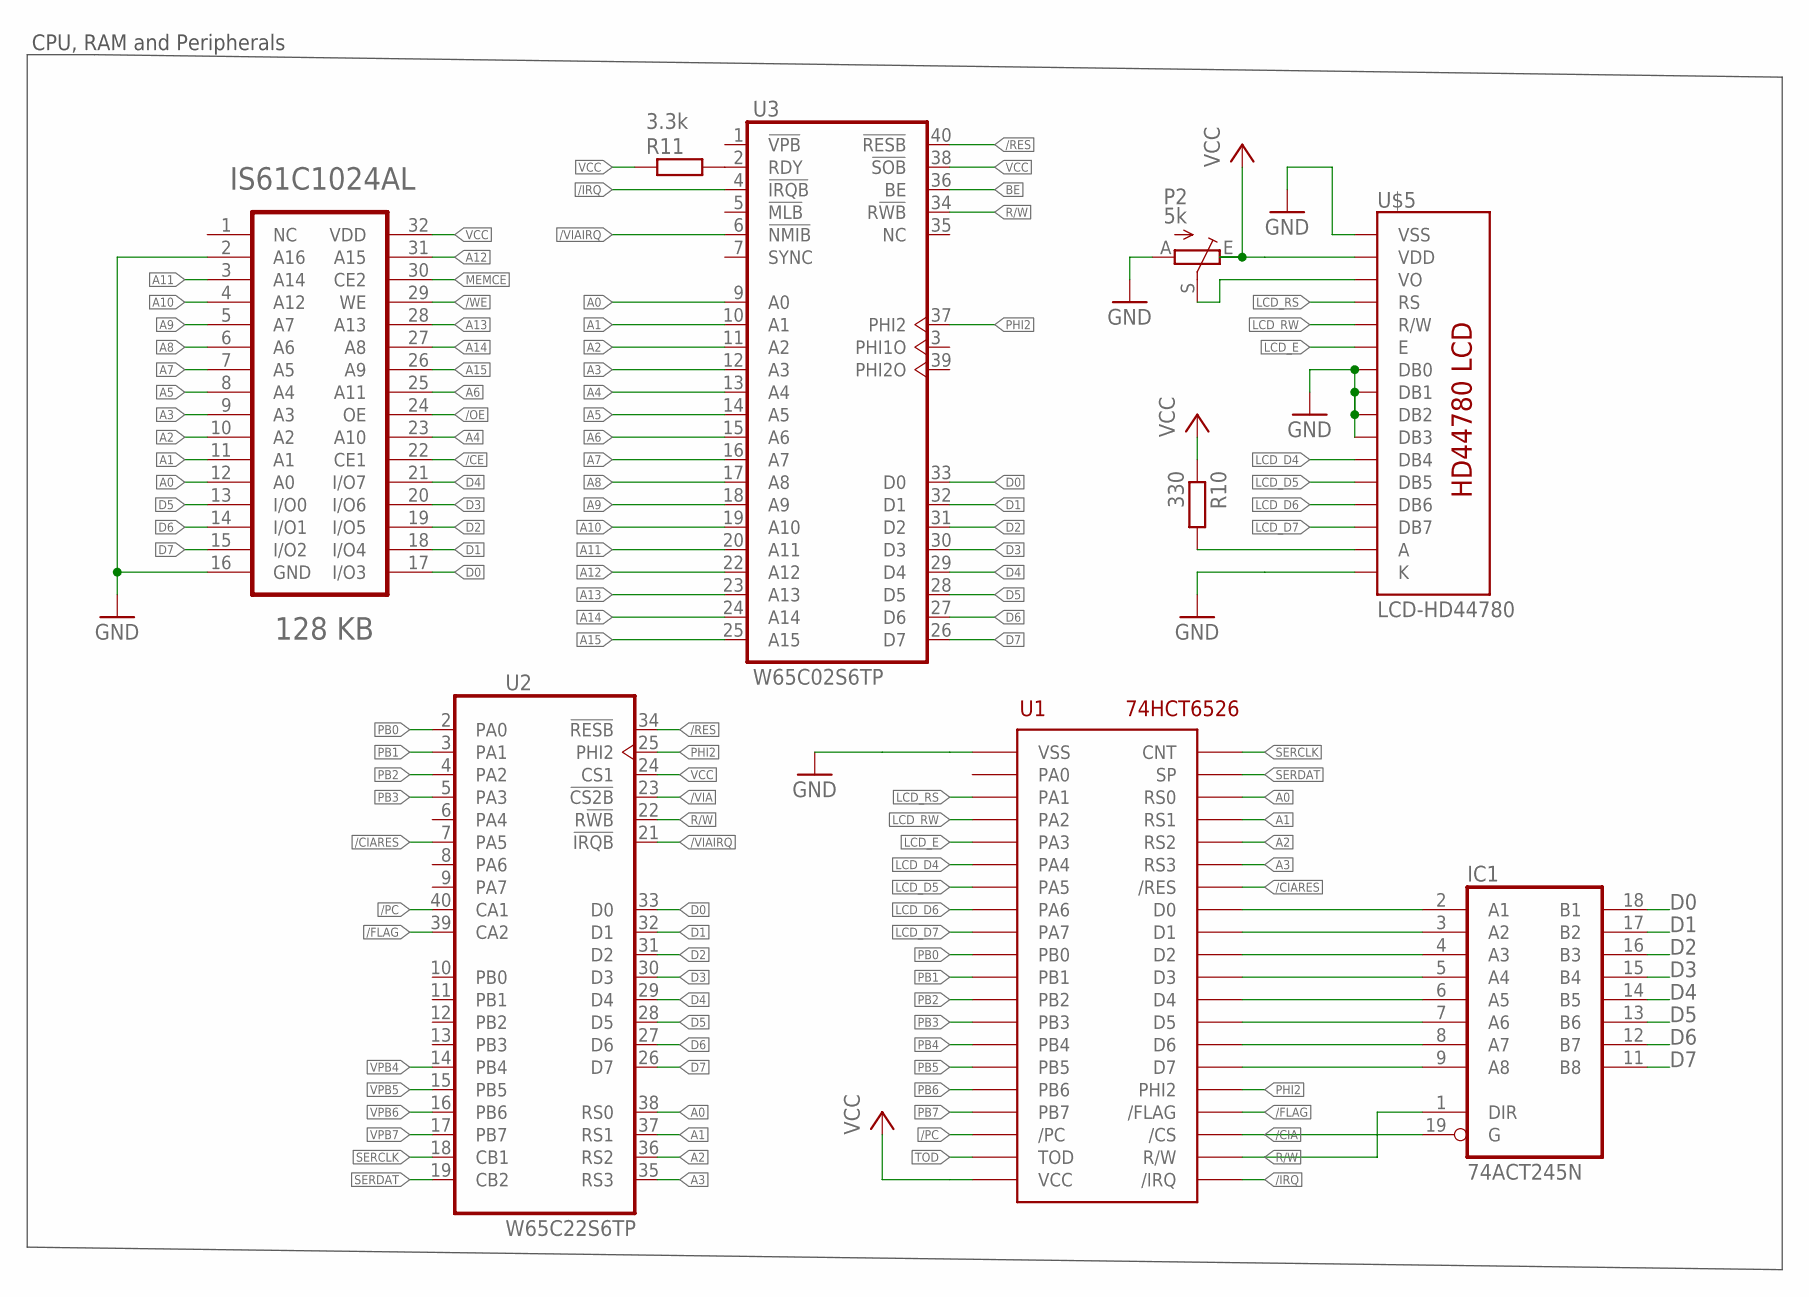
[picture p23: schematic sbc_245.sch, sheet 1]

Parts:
IC1: 74ACT245N; DIL20
P2: 5k; B64Y
R10: 330; R0805
R11: 3.3k; R0805
U1: 74HCT6526; DIP40
U2: W65C22S6TP; DIL40
U3: W65C02S6TP; DIL40
U4: IS61C1024AL-12JLI-TR; SOJ32/3
U$5: LCD-HD44780; LCD-20X4-4HOLES2X8

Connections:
/CE: U4.22 (CE1); also elsewhere on the board
/CIA: IC1.19 (G), U1.23 (/CS); also elsewhere on the board
/CIARES: U1.34 (/RES), U2.7 (PA5)
/FLAG: U1.24 (/FLAG), U2.39 (CA2)
/IRQ: U1.21 (/IRQ), U3.4 (!IRQB)
/OE: U4.24 (OE); also elsewhere on the board
/PC: U1.18 (/PC), U2.40 (CA1)
/RES: U2.34 (!RESB), U3.40 (!RESB); also elsewhere on the board
/VIA: U2.23 (!CS2B); also elsewhere on the board
/VIAIRQ: U2.21 (!IRQB), U3.6 (!NMIB)
/WE: U4.29 (WE); also elsewhere on the board
A0: U1.38 (RS0), U2.38 (RS0), U3.9 (A0), U4.12 (A0); also elsewhere on the board
A1: U1.37 (RS1), U2.37 (RS1), U3.10 (A1), U4.11 (A1); also elsewhere on the board
A2: U1.36 (RS2), U2.36 (RS2), U3.11 (A2), U4.10 (A2); also elsewhere on the board
A3: U1.35 (RS3), U2.35 (RS3), U3.12 (A3), U4.9 (A3); also elsewhere on the board
A4: U3.13 (A4), U4.23 (A10); also elsewhere on the board
A5: U3.14 (A5), U4.8 (A4); also elsewhere on the board
A6: U3.15 (A6), U4.25 (A11); also elsewhere on the board
A7: U3.16 (A7), U4.7 (A5); also elsewhere on the board
A8: U3.17 (A8), U4.6 (A6); also elsewhere on the board
A9: U3.18 (A9), U4.5 (A7); also elsewhere on the board
A10: U3.19 (A10), U4.4 (A12); also elsewhere on the board
A11: U3.20 (A11), U4.3 (A14); also elsewhere on the board
A12: U3.22 (A12), U4.31 (A15); also elsewhere on the board
A13: U3.23 (A13), U4.28 (A13); also elsewhere on the board
A14: U3.24 (A14), U4.27 (A8); also elsewhere on the board
A15: U3.25 (A15), U4.26 (A9); also elsewhere on the board
BE: U3.36 (BE); also elsewhere on the board
D0: IC1.18 (B1), U2.33 (D0), U3.33 (D0), U4.17 (I/O3); also elsewhere on the board
D1: IC1.17 (B2), U2.32 (D1), U3.32 (D1), U4.18 (I/O4); also elsewhere on the board
D2: IC1.16 (B3), U2.31 (D2), U3.31 (D2), U4.19 (I/O5); also elsewhere on the board
D3: IC1.15 (B4), U2.30 (D3), U3.30 (D3), U4.20 (I/O6); also elsewhere on the board
D4: IC1.14 (B5), U2.29 (D4), U3.29 (D4), U4.21 (I/O7); also elsewhere on the board
D5: IC1.13 (B6), U2.28 (D5), U3.28 (D5), U4.13 (I/O0); also elsewhere on the board
D6: IC1.12 (B7), U2.27 (D6), U3.27 (D6), U4.14 (I/O1); also elsewhere on the board
D7: IC1.11 (B8), U2.26 (D7), U3.26 (D7), U4.15 (I/O2); also elsewhere on the board
GND: IC1.10 (GND), P2.A, U1.1 (VSS), U4.2 (A16), U4.16 (GND), U$5.P$1 (VSS), U$5.P$7 (DB0), U$5.P$8 (DB1), U$5.P$9 (DB2), U$5.P$10 (DB3), U$5.P$16 (K); also elsewhere on the board
LCDA: R10.2, U$5.P$15 (A)
LCD_D4: U1.6 (PA4), U$5.P$11 (DB4)
LCD_D5: U1.7 (PA5), U$5.P$12 (DB5)
LCD_D6: U1.8 (PA6), U$5.P$13 (DB6)
LCD_D7: U1.9 (PA7), U$5.P$14 (DB7)
LCD_E: U1.5 (PA3), U$5.P$6 (E)
LCD_RS: U1.3 (PA1), U$5.P$4 (RS)
LCD_RW: U1.4 (PA2), U$5.P$5 (R/W)
MEMCE: U4.30 (CE2); also elsewhere on the board
unnamed: IC1.2 (A1), U1.33 (D0)
unnamed: IC1.3 (A2), U1.32 (D1)
unnamed: IC1.4 (A3), U1.31 (D2)
unnamed: IC1.5 (A4), U1.30 (D3)
unnamed: IC1.6 (A5), U1.29 (D4)
unnamed: P2.S, U$5.P$3 (VO)
unnamed: IC1.7 (A6), U1.28 (D5)
unnamed: IC1.8 (A7), U1.27 (D6)
unnamed: R11.2, U3.2 (RDY)
unnamed: IC1.9 (A8), U1.26 (D7)
PB0: U1.10 (PB0), U2.2 (PA0); also elsewhere on the board
PB1: U1.11 (PB1), U2.3 (PA1); also elsewhere on the board
PB2: U1.12 (PB2), U2.4 (PA2); also elsewhere on the board
PB3: U1.13 (PB3), U2.5 (PA3); also elsewhere on the board
PB4: U1.14 (PB4); also elsewhere on the board
PB5: U1.15 (PB5); also elsewhere on the board
PB6: U1.16 (PB6); also elsewhere on the board
PB7: U1.17 (PB7); also elsewhere on the board
PHI2: U1.25 (PHI2), U2.25 (PHI2), U3.37 (PHI2); also elsewhere on the board
R/W: IC1.1 (DIR), U1.22 (R/W), U2.22 (R!WB), U3.34 (R!WB); also elsewhere on the board
SERCLK: U1.40 (CNT), U2.18 (CB1)
SERDAT: U1.39 (SP), U2.19 (CB2)
TOD: U1.19 (TOD); also elsewhere on the board
VCC: IC1.20 (VCC), P2.E, R10.1, R11.1, U1.20 (VCC), U2.24 (CS1), U3.38 (!SOB), U4.32 (VDD), U$5.P$2 (VDD); also elsewhere on the board
VPB4: U2.14 (PB4); also elsewhere on the board
VPB5: U2.15 (PB5); also elsewhere on the board
VPB6: U2.16 (PB6); also elsewhere on the board
VPB7: U2.17 (PB7); also elsewhere on the board

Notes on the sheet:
CPU, RAM and Peripherals

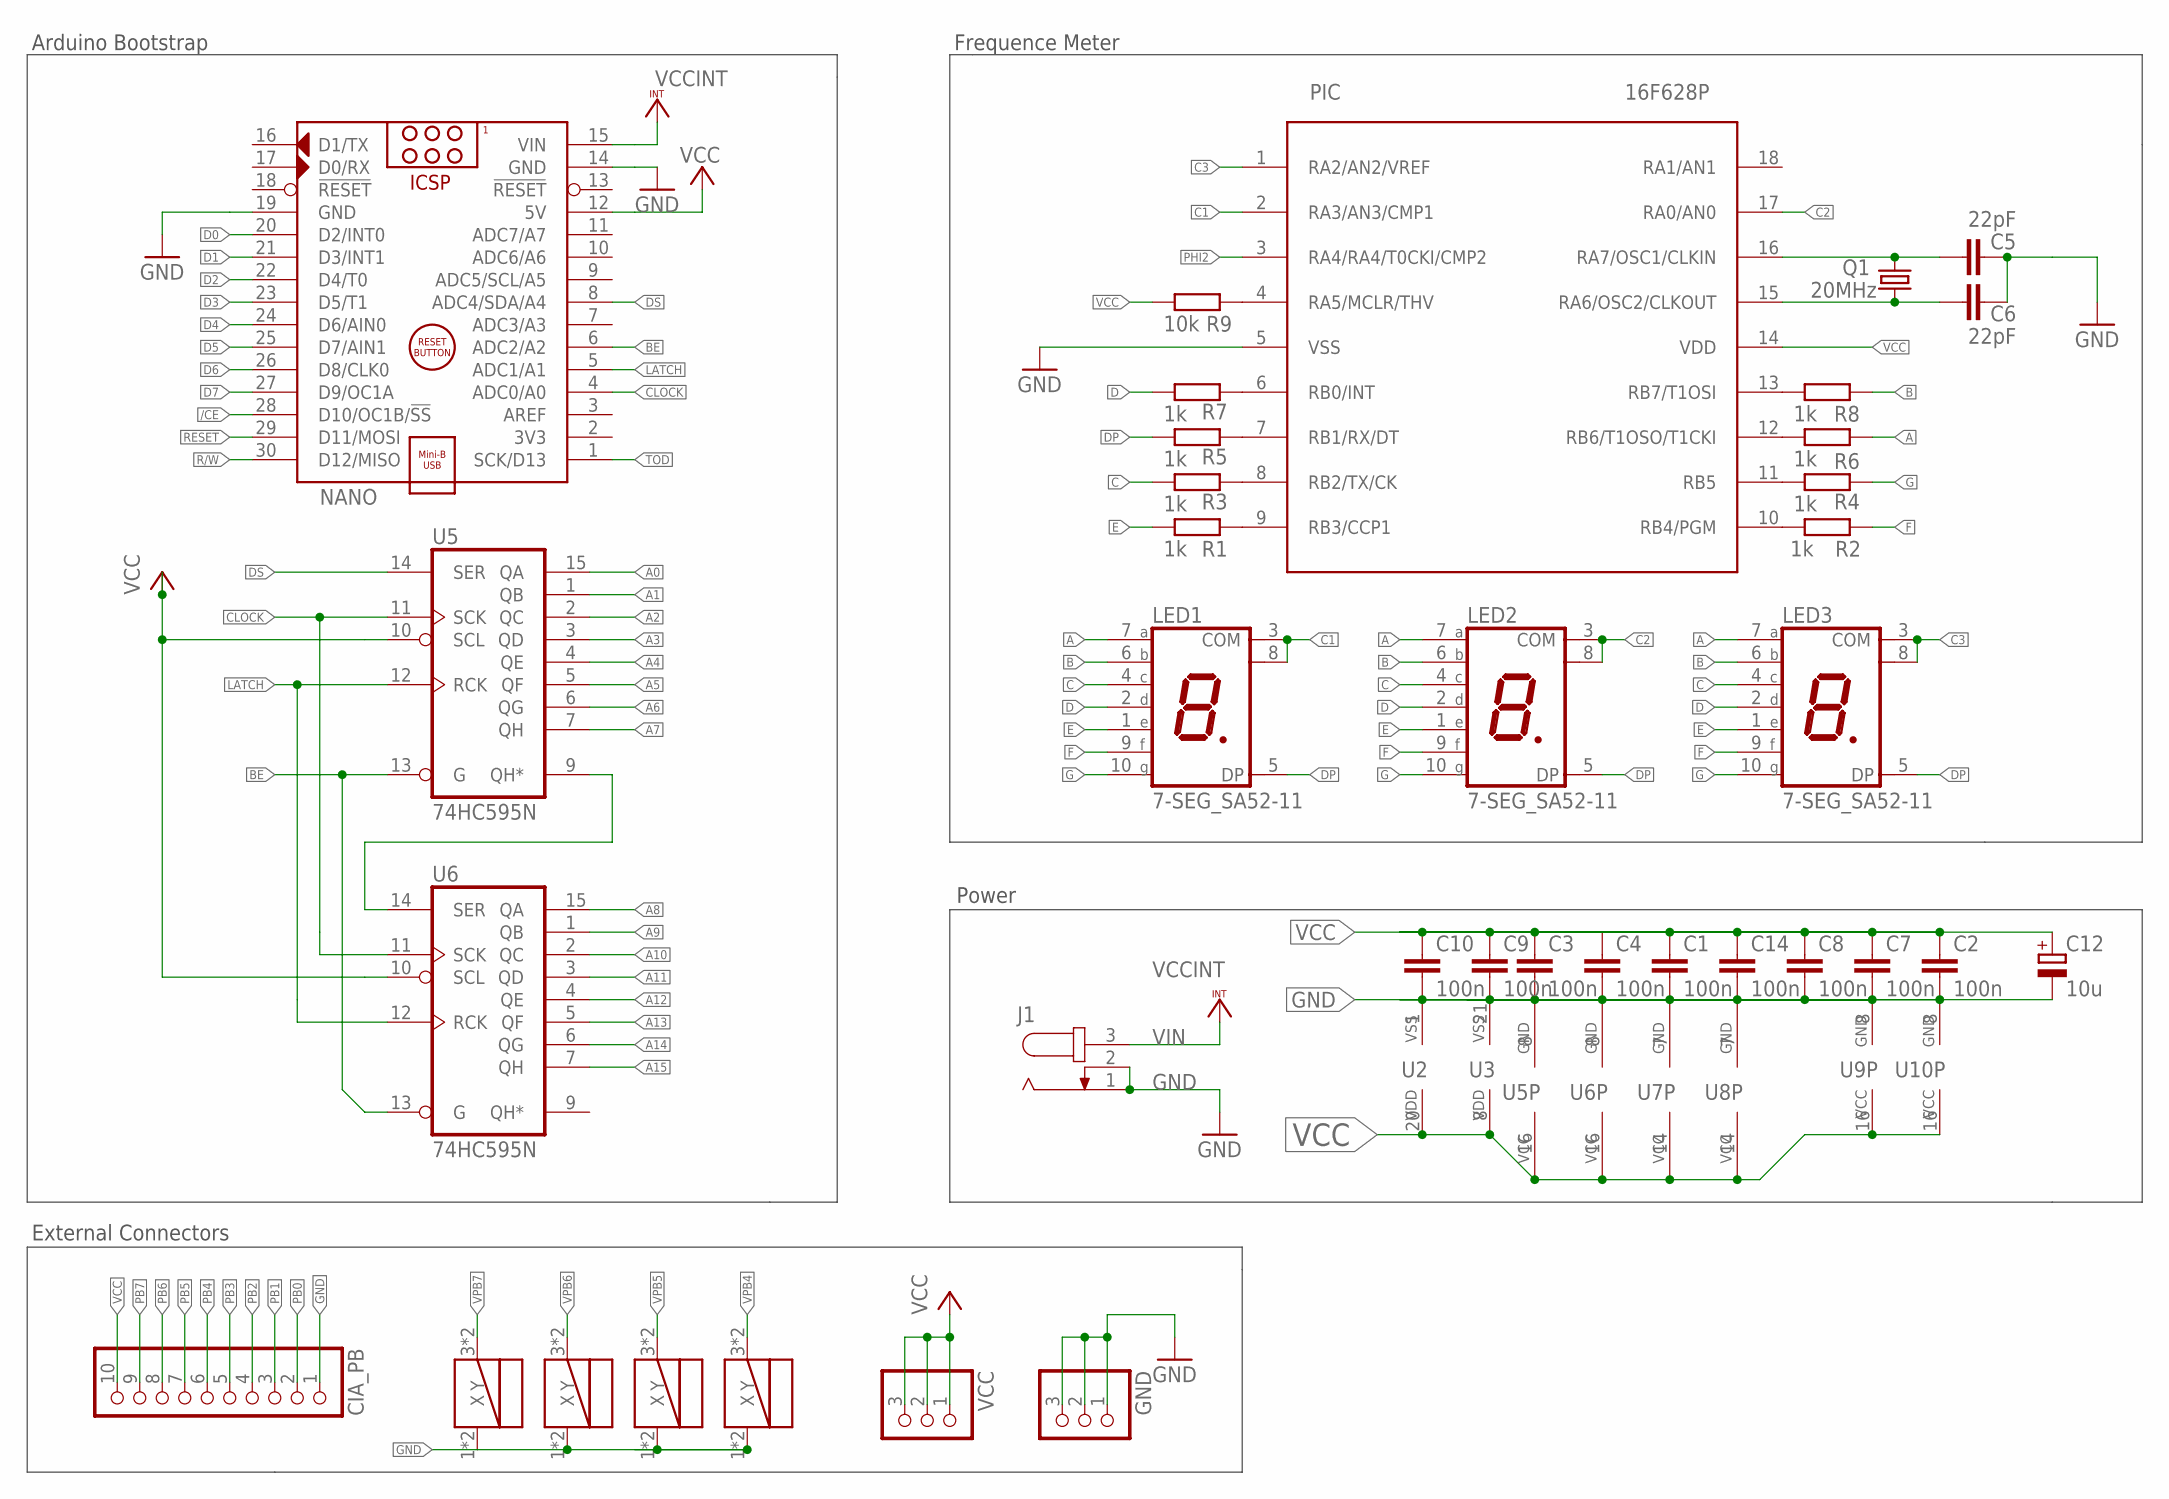
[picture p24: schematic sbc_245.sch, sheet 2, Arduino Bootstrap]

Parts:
C1, C2, C3, C4, C7, C8, C9, C10, C14: 100n; C0805
C5, C6: 22pF; C025-025X050
C12: 10u; B45181A
CIA_PB: PINHD-1X10; 1X10
GND: PINHD-1X3; 1X03
J1: JACK-PLUG0; SPC4077
LED1, LED2, LED3: 7-SEG_SA52-11; SA52-11
NANO: ARDUINO_NANO
PIC: 16F628P; DIL18
Q1: 20MHz; HC18U-V
R1, R2, R3, R4, R5, R6, R7, R8: 1k; 0207/7
R9: 10k; R0805
U2: W65C22S6TP; DIL40
U3: W65C02S6TP; DIL40
U5, U6: 74HC595N; SO16
U7: 74AC74D; SO14
U8: 74AC14D; SO14
U9: 74AC139D; SO16
U10: 74AC138D; SO16
U$1, U$2, U$3, U$4: TSA451G90-250
VCC: PINHD-1X3; 1X03

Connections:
/CE: NANO.28 (D10/OC1B/!SS); also elsewhere on the board
A: LED1.7 (A), LED2.7 (A), LED3.7 (A), R6.2
A0: U5.15 (QA); also elsewhere on the board
A1: U5.1 (QB); also elsewhere on the board
A2: U5.2 (QC); also elsewhere on the board
A3: U5.3 (QD); also elsewhere on the board
A4: U5.4 (QE); also elsewhere on the board
A5: U5.5 (QF); also elsewhere on the board
A6: U5.6 (QG); also elsewhere on the board
A7: U5.7 (QH); also elsewhere on the board
A8: U6.15 (QA); also elsewhere on the board
A9: U6.1 (QB); also elsewhere on the board
A10: U6.2 (QC); also elsewhere on the board
A11: U6.3 (QD); also elsewhere on the board
A12: U6.4 (QE); also elsewhere on the board
A13: U6.5 (QF); also elsewhere on the board
A14: U6.6 (QG); also elsewhere on the board
A15: U6.7 (QH); also elsewhere on the board
B: LED1.6 (B), LED2.6 (B), LED3.6 (B), R8.2
BE: NANO.6 (ADC2/A2), U5.13 (G), U6.13 (G); also elsewhere on the board
C: LED1.4 (C), LED2.4 (C), LED3.4 (C), R3.1
C1: LED1.3 (COM), LED1.8 (COM), PIC.2 (RA3/AN3/CMP1)
C2: LED2.3 (COM), LED2.8 (COM), PIC.17 (RA0/AN0)
C3: LED3.3 (COM), LED3.8 (COM), PIC.1 (RA2/AN2/VREF)
CLOCK: NANO.4 (ADC0/A0), U5.11 (SCK), U6.11 (SCK)
D: LED1.2 (D), LED2.2 (D), LED3.2 (D), R7.1
D0: NANO.20 (D2/INT0); also elsewhere on the board
D1: NANO.21 (D3/INT1); also elsewhere on the board
D2: NANO.22 (D4/T0); also elsewhere on the board
D3: NANO.23 (D5/T1); also elsewhere on the board
D4: NANO.24 (D6/AIN0); also elsewhere on the board
D5: NANO.25 (D7/AIN1); also elsewhere on the board
D6: NANO.26 (D8/CLK0); also elsewhere on the board
D7: NANO.27 (D9/OC1A); also elsewhere on the board
DP: LED1.5 (DP), LED2.5 (DP), LED3.5 (DP), R5.1
DS: NANO.8 (ADC4/SDA/A4), U5.14 (SER)
E: LED1.1 (E), LED2.1 (E), LED3.1 (E), R1.1
F: LED1.9 (F), LED2.9 (F), LED3.9 (F), R2.1
G: LED1.10 (G), LED2.10 (G), LED3.10 (G), R4.2
GND: C1.2, C2.2, C3.2, C4.2, C5.2, C6.2, C7.2, C8.2, C9.2, C10.2, C12.-, C14.2, CIA_PB.1, GND.1, GND.2, GND.3, J1.1, J1.2, NANO.14 (GND), NANO.19 (GND), PIC.5 (VSS), U2.1 (VSS), U3.21 (VSS), U5.8 (GND), U6.8 (GND), U7.7 (GND), U8.7 (GND), U9.8 (GND), U10.8 (GND), U$1.1 (X), U$1.2 (X), U$2.1 (X), U$2.2 (X), U$3.1 (X), U$3.2 (X), U$4.1 (X), U$4.2 (X); also elsewhere on the board
LATCH: NANO.5 (ADC1/A1), U5.12 (RCK), U6.12 (RCK)
unnamed: U5.9 (QH*), U6.14 (SER)
unnamed: PIC.6 (RB0/INT), R7.2
unnamed: PIC.7 (RB1/RX/DT), R5.2
unnamed: PIC.8 (RB2/TX/CK), R3.2
unnamed: PIC.9 (RB3/CCP1), R1.2
unnamed: PIC.10 (RB4/PGM), R2.2
unnamed: PIC.11 (RB5), R4.1
unnamed: PIC.12 (RB6/T1OSO/T1CKI), R6.1
unnamed: PIC.13 (RB7/T1OSI), R8.1
unnamed: C5.1, PIC.16 (RA7/OSC1/CLKIN), Q1.2
unnamed: C6.1, PIC.15 (RA6/OSC2/CLKOUT), Q1.1
unnamed: PIC.4 (RA5/MCLR/THV), R9.2
PB0: CIA_PB.2; also elsewhere on the board
PB1: CIA_PB.3; also elsewhere on the board
PB2: CIA_PB.4; also elsewhere on the board
PB3: CIA_PB.5; also elsewhere on the board
PB4: CIA_PB.6; also elsewhere on the board
PB5: CIA_PB.7; also elsewhere on the board
PB6: CIA_PB.8; also elsewhere on the board
PB7: CIA_PB.9; also elsewhere on the board
PHI2: PIC.3 (RA4/RA4/T0CKI/CMP2); also elsewhere on the board
R/W: NANO.30 (D12/MISO); also elsewhere on the board
RESET: NANO.29 (D11/MOSI); also elsewhere on the board
TOD: NANO.1 (SCK/D13); also elsewhere on the board
VCC: C1.1, C2.1, C3.1, C4.1, C7.1, C8.1, C9.1, C10.1, C12.+, C14.1, CIA_PB.10, NANO.12 (5V), PIC.14 (VDD), R9.1, U2.20 (VDD), U3.8 (VDD), U5.10 (SCL), U5.16 (VCC), U6.10 (SCL), U6.16 (VCC), U7.14 (VCC), U8.14 (VCC), U9.16 (VCC), U10.16 (VCC), VCC.1, VCC.2, VCC.3; also elsewhere on the board
VIN: J1.3, NANO.15 (VIN)
VPB4: U$4.3 (Y), U$4.4 (Y); also elsewhere on the board
VPB5: U$3.3 (Y), U$3.4 (Y); also elsewhere on the board
VPB6: U$2.3 (Y), U$2.4 (Y); also elsewhere on the board
VPB7: U$1.3 (Y), U$1.4 (Y); also elsewhere on the board

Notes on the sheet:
Arduino Bootstrap
Frequence Meter
Power
External Connectors


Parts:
C11: 4,7uF; C0805
C13: 470pF; C0805
P1: 2k; B64Y
R12: 5,6k; R0805
R13, R14: 27k; R0805
SW1: TSA451G90-250
U7: 74AC74D; SO14
U8: 74AC14D; SO14
U9: 74AC139D; SO16
U10: 74AC138D; SO16

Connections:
/CIA: U10.14 (Y1); also elsewhere on the board
/OE: U9.10 (Y2); also elsewhere on the board
/PHI2: U7.8 (!Q), U7.12 (D), U9.14 (A)
/RES: U8.12 (O); also elsewhere on the board
/VIA: U10.13 (Y2); also elsewhere on the board
/WE: U9.12 (Y0); also elsewhere on the board
A11: U10.1 (A); also elsewhere on the board
A12: U10.2 (B); also elsewhere on the board
A13: U10.3 (C); also elsewhere on the board
A14: U9.2 (A), U10.4 (G2A), U10.5 (G2B); also elsewhere on the board
A15: U9.3 (B), U10.6 (G1); also elsewhere on the board
GND: C13.2, R14.1, U8.5 (I), U8.9 (I), U8.11 (I), U9.1 (G), U9.15 (G); also elsewhere on the board
MEMCE: U9.6 (Y2); also elsewhere on the board
unnamed: P1.S, U8.2 (O), U8.3 (I)
unnamed: U7.11 (CLK), U8.4 (O)
unnamed: C13.1, P1.E, U8.1 (I)
unnamed: R13.1, R14.2, SW1.3 (Y), SW1.4 (Y)
unnamed: C11.2, R12.1, R13.2
PHI2: U7.9 (Q); also elsewhere on the board
R/W: U9.13 (B); also elsewhere on the board
RESET: R12.2, U8.13 (I); also elsewhere on the board
VCC: C11.1, SW1.1 (X), SW1.2 (X), U7.1 (CLR), U7.2 (D), U7.3 (CLK), U7.4 (PRE), U7.10 (PRE), U7.13 (CLR); also elsewhere on the board

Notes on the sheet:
11xx xxxx xxxx xxxx RAM C000 - ffff 1001 0xxx xxxx xxxx VIA 9000 - 97ff 1000 1xxx xxxx xxxx CIA 8800 - 8fff 1000 0xxx xxxx xxxx LCD 8000 - 87ff 0xxx xxxx xxxx xxxx RAM 0000 - 7fff
Reset Button
Reset from Arduino
To 65xx Devices
Address Decoder
Unused Gates
Clock Generator
Reset Generator



Board: 2 copper layers, 100.0 x 100.0 mm, 57 parts (7 on the bottom side), 108 nets.

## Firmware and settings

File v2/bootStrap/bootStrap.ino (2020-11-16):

/**********************************
 * ROM PROGRAMMER FOR SBC TESTBED *
 **********************************/

// Define control signals
#define TOD   13
#define CLOCK 14
#define LATCH 15
#define BE    16
#define DS    18
#define TODE  21
#define D0    2
#define D1    3
#define D2    4
#define D3    5
#define D4    6
#define D5    7
#define D6    8
#define D7    9
#define RESET 11
#define CE    10
#define RW    12

// Buffer for serial buik write 
#define BUFFERSIZE 1024
byte buffer[BUFFERSIZE];

/**********************************
 * SETUP
 */

void setup() {

  // Configure TIMER1 to generate a 60Hz Interrupt
    cli();                      // stop interrupts
    TCCR1A = 0;                 // set entire TCCR1A register to 0
    TCCR1B = 0;                 // same for TCCR1B
    TCNT1  = 0;                 // initialize counter value to 0
  // set compare match register for 60 Hz increments
    OCR1A = 33332;              // = 16000000 / (8 * 60) - 1 
  // turn on CTC mode
    TCCR1B |= (1 << WGM12);
  // Set CS12, CS11 and CS10 bits for 8 prescaler
    TCCR1B |= (0 << CS12) | (1 << CS11) | (0 << CS10);
  // enable timer compare interrupt
    TIMSK1 |= (1 << OCIE1A);
    sei();                      // allow interrupts
   
  // Configure control signals
    pinMode(RESET, INPUT);
    digitalWrite (RESET, HIGH);
    pinMode(CE, OUTPUT);
    digitalWrite (CE, LOW);
    pinMode(RW, OUTPUT);
    digitalWrite (RW, HIGH);

  // Shift Registers
    pinMode(CLOCK, OUTPUT);
    digitalWrite(CLOCK, LOW);
    pinMode(LATCH, OUTPUT);
    digitalWrite(LATCH, LOW);
    pinMode(DS, OUTPUT);
    digitalWrite(DS, LOW);

  // BE acts as bus arbitrer
  // BE HIGH : Shift Registers disabled   65c02 enabled   >>  65c02 owns the bus  
  // BE LOW  : Shift Registers enabled    65c02 disabled  >>  Nano  owns the bus
    pinMode(BE, OUTPUT);
    digitalWrite(BE, LOW);

  // Data Bus. Start as input to avoid bus contention
    pinMode(D0, INPUT);
    pinMode(D1, INPUT);
    pinMode(D2, INPUT);
    pinMode(D3, INPUT);
    pinMode(D4, INPUT);
    pinMode(D5, INPUT);
    pinMode(D6, INPUT);
    pinMode(D7, INPUT);

  // Initialize Serial Port
    Serial.begin(115200);
}

ISR(TIMER1_COMPA_vect){
  // timer interrupt to toggle TOD
  // TO-DO if todenable=1, set pin as input
  if (analogRead(7) > 250) 
    pinMode (TOD, INPUT);
  else
    pinMode (TOD, OUTPUT);
  
    PINB = PINB | 0b00100000; // toggle TOD
    PINB = PINB | 0b00100000; // toggle TOD
}

// REVISAR








//faster shiftOut function then normal IDE function (about 4 times)
void fastShiftOut (byte data) {
  //clear data pin
  bitClear(PORTC,4);
  //Send each bit of the myDataOut byte MSBFIRST
  for (int i=7; i>=0; i--)  {
    bitClear(PORTC,0);
    //--- Turn data on or off based on value of bit
    if ( bitRead(data,i) == 1) {
      bitSet(PORTC,4);
    }
    else {      
      bitClear(PORTC,4);
    }
    //register shifts bits on upstroke of clock pin  
    bitSet(PORTC,0);
    //zero the data pin after shift to prevent bleed through
    bitClear(PORTC,4);
  }
  //stop shifting
  bitClear(PORTC,0);
}


// Modo lectura
void readMem() {
  digitalWrite(RW, HIGH);
}

// Modo escritura
void writeMem() {
  digitalWrite(RW, LOW);
}

// Pone byte en el data Bus
void setData(byte value) {
  //2 bits belong to PORTB and have to be set separtely
  digitalWrite(D0, (value >> 0) & 0x01);
  digitalWrite(D1, (value >> 1) & 0x01);
  digitalWrite(D2, (value >> 2) & 0x01);
  digitalWrite(D3, (value >> 3) & 0x01);
  digitalWrite(D4, (value >> 4) & 0x01);
  digitalWrite(D5, (value >> 5) & 0x01);
  digitalWrite(D6, (value >> 6) & 0x01);
  digitalWrite(D7, (value >> 7) & 0x01);
}

byte readAddress(long address)
{
  setBusInput();
  readMem();
  setAddress(address);
  delay(1);
  byte ret = read_data_bus();
  delay(1);
  return ret;
}

void writeAddress(long address, byte value) {
  setAddress(address);
  setData(value);
  digitalWrite(RW, LOW);
  setBusOutput();
  digitalWrite(RW, HIGH);
  setBusInput();
}

/**********************************
   SERIAL COMMS
*/

//command buffer for parsing commands
#define COMMANDSIZE 32
char cmdbuf[COMMANDSIZE];

//waits for a string submitted via serial connection
//returns only if linebreak is sent or the buffer is filled
void readCommand() {
  //first clear command buffer
  for (int i = 0; i < COMMANDSIZE; i++) cmdbuf[i] = 0;
  //initialize variables
  char c = ' ';
  int idx = 0;
  //now read serial data until linebreak or buffer is full
  do {
    if (Serial.available()) {
      c = Serial.read();
      cmdbuf[idx++] = c;
    }
  }
  while (c != '\n' && idx < (COMMANDSIZE)); //save the last '\0' for string end
  //change last newline to '\0' termination
  cmdbuf[idx - 1] = 0;
}

byte hexDigit(char c)
{
  if (c >= '0' && c <= '9') {
    return c - '0';
  }
  else if (c >= 'a' && c <= 'f') {
    return c - 'a' + 10;
  }
  else if (c >= 'A' && c <= 'F') {
    return c - 'A' + 10;
  }
  else {
    return 0;   // getting here is bad: it means the character was invalid
  }
}

unsigned int hexWord(char* data) {
  return ((hexDigit(data[0]) * 4096) +
          (hexDigit(data[1]) * 256) +
          (hexDigit(data[2]) * 16) +
          (hexDigit(data[3])));
}

byte hexByte(char* a)
{
  return ((hexDigit(a[0]) * 16) + hexDigit(a[1]));
}

/**********************************
   MAIN LOOP
*/

void loop() {
  readCommand();
  String outputString;

  // CMDBUF
  // 0123456789ABCD
  // W FFFF FF FFFF
  //First string is command
  cmdbuf[1]  = 0;
  //second string is address (4 bytes)
  cmdbuf[6]  = 0;
  //third string is byte (2 bytes)
  cmdbuf[9] = 0;
  //4th is end address
  cmdbuf[14] = 0;

  unsigned int Address = hexWord(cmdbuf + 2);
  unsigned int Value = hexByte(cmdbuf + 7);
  unsigned int Length = hexWord(cmdbuf + 10);
  switch (cmdbuf[0]) {
    case 'A':
      outputString = outputString + "A:" + Address;
      setAddress(Address);
      break;
    case 'R':
      outputString = outputString + "READ :" + Address;
      outputString = readAddress(Address);
      break;
    case 'W':
      outputString = outputString + "WRITE :" + Address + " " + Value;
      writeAddress(Address, Value);
      break;
    case 'X':
      outputString = outputString + "RESET";
      pinMode (RESET, OUTPUT);
      digitalWrite (RESET, HIGH);
      pinMode (RW, INPUT_PULLUP);
      setBusInput();
      digitalWrite (BE, HIGH);    // Devolvemos bus al 6502
      delay(50);
      pinMode (RW, INPUT);
      delay(50);
      pinMode (RESET, INPUT);
      outputString = "Reiniciando 6502 y devolviendo bus...";

      break;
    case 'S':
      // STOP
      pinMode(RW, INPUT_PULLUP);
      setAddress(32768);
      digitalWrite (BE, LOW);     // Sacabmos el 6502 del bus
      pinMode(RW, OUTPUT);
      outputString = "Retomando control del bus";
      break;
    case 'B':
      // Bulk
      outputString = "Bulk Start : ";
      outputString = outputString + Address;
      outputString = outputString + " Length : ";
      outputString = outputString + Length;
      Serial.print("@");
      long position = 0;
      while (position < Length) {
        if (Serial.available()) buffer[position++] = Serial.read();
      }
      for (unsigned int i = 0; i < Length; i++) {
        writeAddress(Address + i, buffer[i]);
      }
      break;
    default:
      outputString = "Comando no reconocido";
  }

  Serial.println(outputString);
  Serial.print("@");
}

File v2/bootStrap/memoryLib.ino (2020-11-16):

byte read_data_bus() {
  // Returns current byte on the data bus  
    byte readByte = (
      (digitalRead(D7) << 7) +
      (digitalRead(D6) << 6) +
      (digitalRead(D5) << 5) +
      (digitalRead(D4) << 4) +
      (digitalRead(D3) << 3) +
      (digitalRead(D2) << 2) +
      (digitalRead(D1) << 1) +
      (digitalRead(D0))
    );
    return readByte;
}

void setBusOutput() {
  // Sets data bus as output
    pinMode(D0, OUTPUT);
    pinMode(D1, OUTPUT);
    pinMode(D2, OUTPUT);
    pinMode(D3, OUTPUT);
    pinMode(D4, OUTPUT);
    pinMode(D5, OUTPUT);
    pinMode(D6, OUTPUT);
    pinMode(D7, OUTPUT);
}

void setBusInput() {
  // Sets data bus as input
    pinMode(D0, INPUT);
    pinMode(D1, INPUT);
    pinMode(D2, INPUT);
    pinMode(D3, INPUT);
    pinMode(D4, INPUT);
    pinMode(D5, INPUT);
    pinMode(D6, INPUT);
    pinMode(D7, INPUT);
}

void setAddress (long address) {
  // Sets address bus
    digitalWrite(CLOCK, LOW);
    digitalWrite(LATCH, LOW);
  //get high - byte of 16 bit address
    byte hi = address >> 8;
  //get low - byte of 16 bit address
    byte lo = address & 0xff;
    fastShiftOut (hi);
    fastShiftOut (lo);
    digitalWrite(LATCH, HIGH);
}

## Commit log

2020-11-16 Re-creation
    Repository has been recreated to add a new (still WIP) v2 version.
    [20X4LCD JHD204A.STEP, bootstrap.sch, clock.sch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]
2020-11-27 All nets verified
    All nets have been verified against all design. Even though v2 is not tested yet, at least, the schematic is correct.
    [peripherals.sch, power.sch, sbc6526.kicad_pcb]
2020-12-11 new revision - dual 6526
    new revision - dual 6526
    [memory.sch, peripherals.sch, sbc6526.kicad_pcb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]
2020-12-15 Changing to Dual CIA
    [bootstrap.sch, clockmeter.sch, memory.sch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]
